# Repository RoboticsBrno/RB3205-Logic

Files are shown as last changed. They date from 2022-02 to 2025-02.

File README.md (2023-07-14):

# About Logic

Logic is a universal programmable toy designed for teaching programming
developed at [Robotárna](https://helceletka.cz/robotarna).

Logic resembles a game console. It has 105 RGB LEDs that can serve as a display, it
has numerous buttons and a buzzer. Under the hood, it is powered by the ESP32
microcontroller.

Kids (well, not only them) can create custom games and
learn programming while doing so. It is even possible to run multiplayer games as the on-board
processor features both, WiFi and Bluetooth 4.

This project was prepared for [Robotic Camp 2021](https://2021.robotickytabor.cz/) ­–
the page is available, however, in Czech. You will find more project there. You
can also see our [GitHub](https://github.com/RoboticsBrno) for find out more
about our other projects.

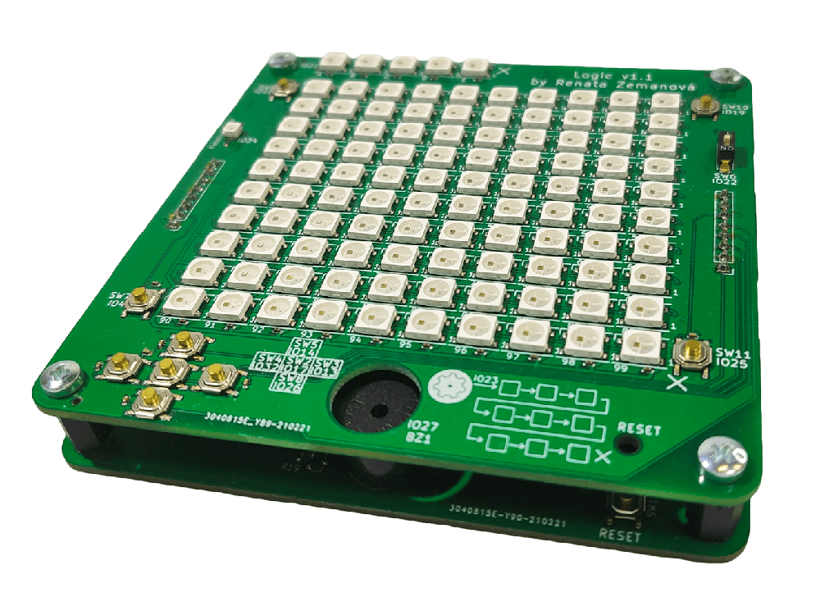
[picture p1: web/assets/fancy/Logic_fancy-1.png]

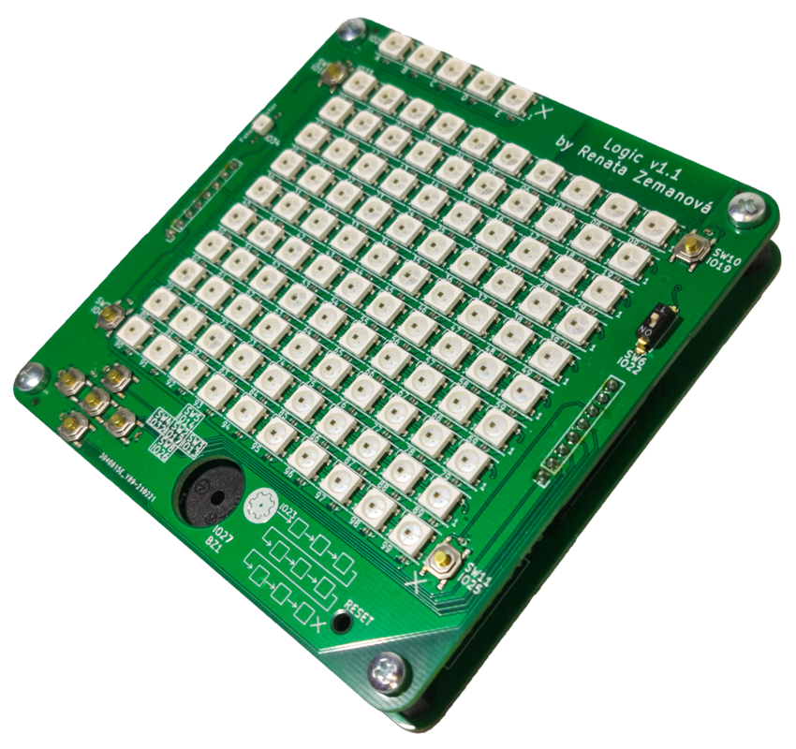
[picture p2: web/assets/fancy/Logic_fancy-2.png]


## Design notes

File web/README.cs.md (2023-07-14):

# Logic

Logic je univerzální programovatelná hračka určená pro výuku programování, kterou vyvinula [Robotárna](https://helceletka.cz/robotarna).

Logic připomíná herní konzoli. Je vybavený 105 RGB LED diodami, které mohou sloužit jako displej, má mnoho tlačítek a bzučák. Vnitřní část pohání mikrořadič ESP32.

Děti (no, nejen ony) mohou vytvářet vlastní hry a učit se přitom programovat. Je dokonce možné spouštět multiplayerové hry, protože vestavěný procesor podporuje jak WiFi, tak Bluetooth 4.

Tento projekt byl připraven pro [Robotický tábor 2021](https://2021.robotickytabor.cz/) – stránka je dostupná, avšak v češtině. Najdete tam více projektů. Můžete se také podívat na náš [GitHub](https://github.com/RoboticsBrno), kde se dozvíte více o našich dalších projektech.

## Verze HW

Existuje několik verzí HW, přičemž druhá verze představuje zásadní přepracování.

### Seznam změn:

#### v2.0

- nový čip ESP32 S3 (namísto "normálního" ESP32)
- slot pro [SD kartu](code/sdcard.md)
- konektor [PMOD](code/pmod.md) (standardizované rozhraní pro připojení různých periferií)
- přepracované uspořádání tlačítek s dvěma směrovými kříži
- piezo místo pouhého bzučáku (takže můžete přehrávat různé tóny)
- jasnější inteligentní LED

=== "Logic v2"
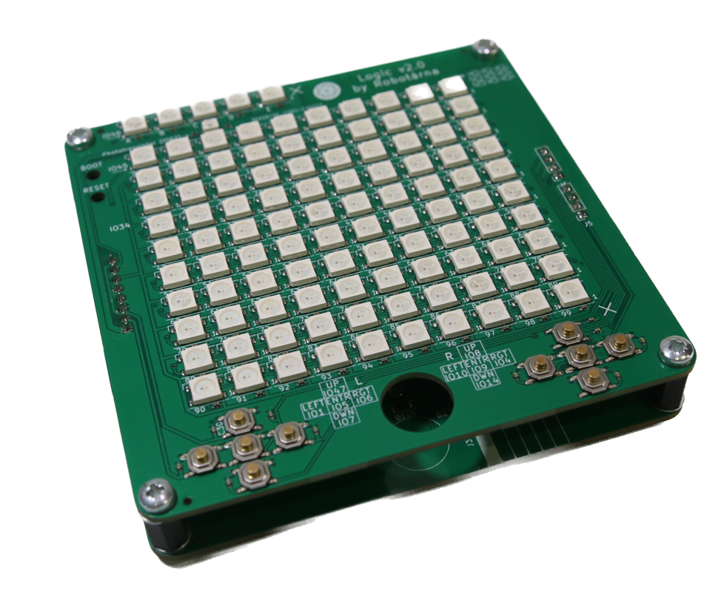
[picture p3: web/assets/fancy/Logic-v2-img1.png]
	
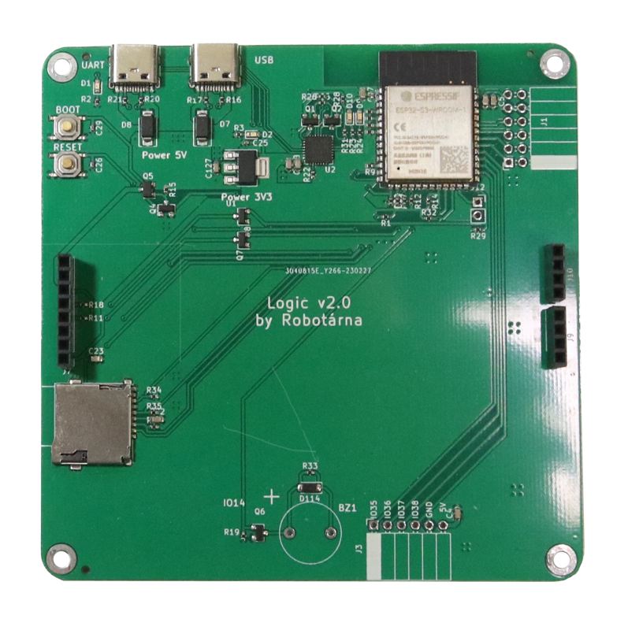
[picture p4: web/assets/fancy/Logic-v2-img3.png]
	
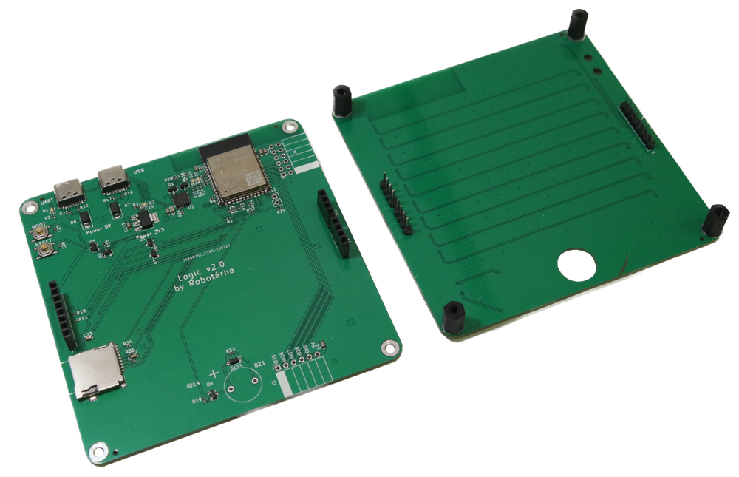
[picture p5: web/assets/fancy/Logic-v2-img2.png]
	

=== "Logic v1"
	RoboSvit schéma
	RoboSvit schéma

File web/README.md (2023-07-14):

# About Logic

Logic is a universal programmable toy designed for teaching programming
developed at [Robotárna](https://helceletka.cz/robotarna).

Logic resembles a game console. It has 105 RGB LEDs that can serve as a display, it
has numerous buttons and a buzzer. Under the hood, it is powered by the ESP32
microcontroller.

Kids (well, not only them) can create custom games and
learn programming while doing so. It is even possible to run multiplayer games as the on-board
processor features both, WiFi and Bluetooth 4.

This project was prepared for [Robotic Camp 2021](https://2021.robotickytabor.cz/) ­–
the page is available, however, in Czech. You will find more project there. You
can also see our [GitHub](https://github.com/RoboticsBrno) for find out more
about our other projects.

## HW revisions

There are multiple HW revisions out in the wild, with the v2 being a major overhaul.

### Changelog:

#### v2.0

- new ESP32 S3 chip (instead of "normal" ESP32)
- [SD Card slot](code/sdcard.md)
- [PMOD connector](code/pmod.md) (a standardized interface to connect various peripherials)
- revised button layout with two direction crosses
- piezo instead of just a buzzer (so you can play different tones)
- brighther smart LEDs

=== "Logic v2"
	RoboSvit schéma
	RoboSvit schéma
	RoboSvit schéma

=== "Logic v1"
	RoboSvit schéma
	RoboSvit schéma

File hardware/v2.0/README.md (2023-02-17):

# About Logic

## changes compared to V1.1:
- ESP32-S3
- SD card

<div align="center">
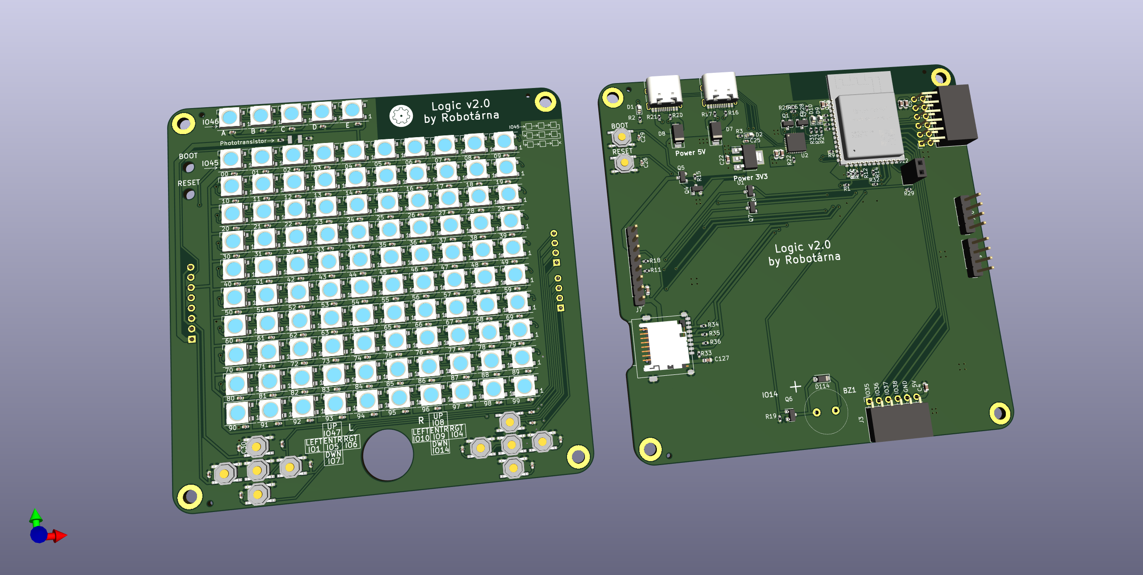
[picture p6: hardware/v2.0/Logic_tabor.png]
    
</div>

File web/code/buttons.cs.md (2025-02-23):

# Tlačítka

## Přímé čtení tlačítek

- **`buttons.read(gpio_num_t gpio)`** : 

## Názvy tlačítek
- `Enter`
- `Up`
- `Down`
- `Left`
- `Right`
- `LeftUp`
- `LeftDown`
- `RightUp`
- `RightDown`

## Příklad použití

```cpp
#include "Logic.hpp"
#include <iostream>

void logicMain() {
    while (true) {
        display.clear();

        if(buttons.read(Enter)) {
            display.drawSquareFilled(3, 3, 4, Rgb(255, 255, 255));    
        }
        else if(buttons.read(Right)) {
            display.drawSquareFilled(6, 3, 4, Rgb(255, 255, 255));
        }
        else if(buttons.read(Down)) {
            display.drawSquareFilled(3, 6, 4, Rgb(255, 255, 255));
        }
        else if(buttons.read(Left)) {
            display.drawSquareFilled(0, 3, 4, Rgb(255, 255, 255));
        }
        else if(buttons.read(Up)) {
            display.drawSquareFilled(3, 0, 4, Rgb(255, 255, 255));
        }
        display.show(30);
    }
}
```
# Registrace událostí na tlačítka

## buttons.priZmene (buttons.onChange)

```cpp
buttons.priZmene([](std::bitset<MaxID> aktualniStav, std::bitset<MaxID> zmenenaTlacitka) {
	if (zmenenaTlacitka[Up] == 1) {

		std::cout << "Tlačítko Nahoru se změnilo a teď je ";

		if (aktualniStav[Up] == 1) {
			std::cout << "zmáčknuté." << std::endl;
		} else {
			std::cout << "puštěné." << std::endl;
		}
	}
});

buttons.priZmene([](std::bitset<MaxID> aktualniStav) {
	std::cout << "Tlačítko Nahoru je nyní ";

	if (aktualniStav[Up] == 1) {
		std::cout << "zmáčknuté." << std::endl;
	} else {
		std::cout << "puštěné." << std::endl;
	}
});

buttons.priZmene([]() {
	std::cout << "Tlačítko bylo změněno. Není k dispozici více informací." << std::endl;
});

buttons.priZmene([](std::bitset<MaxID> aktualniStav, std::bitset<MaxID> zmenenaTlacitka) {
	std::cout << "Tohle uvidíte pouze pokud se změní tlačítko Dolů, a toto tlačítko je nyní ";

	if (aktualniStav[Down] == 1) {
		std::cout << "zmáčknuté." << std::endl;
	} else {
		std::cout << "puštěné." << std::endl;
	}
}, Down);

buttons.priZmene([](bool isPressed) {
	std::cout << "Tohle uvidíte pouze pokud se změní tlačítko Dolů" << std::endl;

	if (isPressed == 1) {
		std::cout << "zmáčknuté." << std::endl;
	} else {
		std::cout << "puštěné." << std::endl;
	}
}, Down);

buttons.onChange([]() {
	std::cout << "Tohle uvidíte pouze pokud se změní tlačítko Dolů" << std::endl;
}, Down);
```

## buttons.priStisku (buttons.onPress)

```cpp
buttons.priStisku([](std::bitset<MaxID> aktualniStav, std::bitset<MaxID> zmena) {
	std::cout << "Nějaké tlačítko bylo zmáčknuto. ";

	if (zmena[Right] == 1) {
		std::cout << "Bylo to tlačítko Vpravo" << std::endl;
	} else {
		std::cout << "Nebylo to tlačítko Vpravo" << std::endl;
	}
});

buttons.priStisku([](std::bitset<MaxID> aktualniStav) {
	std::cout << "Nějaké tlačítko bylo zmáčknuto. ";

	std::cout << "Tlačítka ";

	for(int i = 0; i < MaxID; i++) {
		if (aktualniStav[i] == 1) {
			std::cout << i << ", ";
		}
	}

	std::cout << "jsou nyní zmáčknutá." << std::endl;
});

buttons.priStisku([]() {
	std::cout << "Tlačítko bylo Zmáčknuto. Není k dispozici více informací." << std::endl;
});

buttons.priStisku([]() {
	std::cout << "Tohle uvidíte pouze pokud zmáčknete tlačítko Vlevo." << std::endl;
}, Left);
```

## buttons.priUvolneni (.onRelease)

```cpp
buttons.priUvolneni([](std::bitset<MaxID> aktualniStav, std::bitset<MaxID> zmena) {
	std::cout << "Tlačítko bylo puštěno. ";

	if (zmena[Right] == 1) {
		std::cout << "Bylo to tlačítko Vpravo" << std::endl;
	} else {
		std::cout << "Nebylo to tlačítko Vpravo" << std::endl;
	}
});

buttons.priUvolneni([](std::bitset<MaxID> aktualniStav) {
	std::cout << "Tlačítko bylo puštěno. ";

	std::cout << "Tlačítka ";

	for(int i = 0; i < MaxID; i++) {
		if (aktualniStav[i] == 0) {
			std::cout << i << ", ";
		}
	}

	std::cout << "jsou nyní puštěná." << std::endl;
});

buttons.priUvolneni([]() {
	std::cout << "Tlačítko bylo uvolněno. Není k dispozici více informací." << std::endl;
});

buttons.priUvolneni([]() {
	std::cout << "Tohle uvidíte pouze pokud pustíte tlačítko Vlevo." << std::endl;
}, Left);
```

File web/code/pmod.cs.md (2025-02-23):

# PMOD konektor

Logic v2 a novější má PMOD konektor, který je standardizovaným způsobem pro připojení
různých periferií.

!!! info

    HW revize 1.x nemají PMOD konektor.

## Zapojení pinů

Zapojení pinů je vyznačeno na spodní straně desky bílými popisky.

!!! warning

    Popisek 5V je chybný a měl by místo toho být `VCC` – napětí je možné konfigurovat, viz níže.

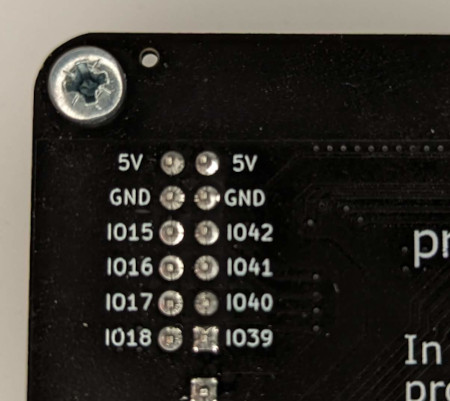
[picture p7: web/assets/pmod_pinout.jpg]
PMOD zapojení pinů


## Nastavení napětí

U HW revize v2.0 se nachází tři pinové lišty pro nastavení napětí na PMOD VCC.
Bohužel nejsou označené, takže zde jsou fotografie nastavení pro 3,3 V a 5 V:

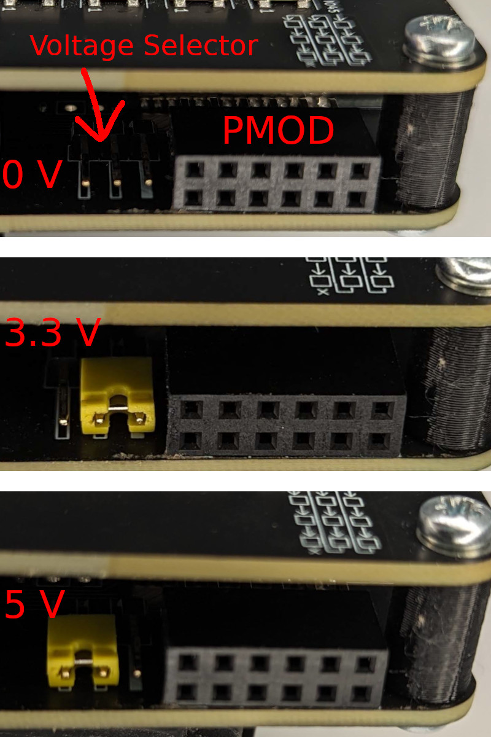
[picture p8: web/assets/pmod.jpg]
PMOD voltage


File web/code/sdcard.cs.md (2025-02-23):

# SD karta

Deska Logic v2 je vybavena slotem pro SD kartu, který můžete použít ke čtení nebo zápisu dat na kartu s FAT32 formátem.

!!! info

    HW revize 1.x nemají slot na SD kartu.

!!! danger "SDMMC je nefunkční"

    U HW revize 2.0 je režim SDMMC nefunkční. K přístupu na SD kartu je nutné použít protokol SDSPI. Tato chyba bude opravena v [pozdější HW revizi](https://github.com/RoboticsBrno/RB3205-Logic/issues/1).

## Zapojení pinů

| Pin | SD SPI | {--SD MMC--} |
| --- | --- | --- |
| 11  | MOSI | {--CMD--} |
| 12  | SCLK | {--CLK--} |
| 13  | MISO | {--D0--} |
| 3 | CS | {--CD--} |

## Ukázkový inicializační kód

Pro SD kartu je zapotřebí delší kód pro inicializaci, ale poté můžete používat standardní funkce jazyka C nebo C++ pro přístup k souborovému systému, podobně jako na běžném počítači.

```cpp
#include "Logic.hpp"
#include <iostream>

#include "esp_vfs_fat.h"
#include <dirent.h>
#include <string.h>
#include <sys/stat.h>
#include <sys/unistd.h>

#define EXAMPLE_MAX_CHAR_SIZE 64

static const char* TAG = "example";

#define MOUNT_POINT "/sdcard"

void logicMain() {
    esp_err_t ret;

    // Inicializace SPI sběrnice
    spi_bus_config_t bus_cfg = {};
    bus_cfg.mosi_io_num = GPIO_NUM_11;
    bus_cfg.miso_io_num = GPIO_NUM_13;
    bus_cfg.sclk_io_num = GPIO_NUM_12;
    bus_cfg.quadwp_io_num = -1;
    bus_cfg.quadhd_io_num = -1;
    bus_cfg.max_transfer_sz = 4000;

    ret = spi_bus_initialize(SPI2_HOST, &bus_cfg, SPI_DMA_CH_AUTO);
    if (ret != ESP_OK) {
        ESP_LOGE(TAG, "Nepodařilo se inicializovat sběrnici.");
        vTaskDelay(1000 / portTICK_PERIOD_MS);
        return;
    }

    /// Možnosti pro souborový systém
    esp_vfs_fat_mount_config_t mount_config = {};
    mount_config.max_files = 5;
    mount_config.allocation_unit_size = 16 * 1024;

    sdmmc_card_t* card;
    const char mount_point[] = MOUNT_POINT;
    ESP_LOGI(TAG, "Inicializace SD karty");

    // Inicializace SDSPI
    sdmmc_host_t host = SDSPI_HOST_DEFAULT();
    host.slot = SPI2_HOST;

    sdspi_device_config_t dev_cfg = SDSPI_DEVICE_CONFIG_DEFAULT();
    dev_cfg.gpio_cs = GPIO_NUM_3;

    ESP_LOGI(TAG, "Připojování souborového systému");
    ret = esp_vfs_fat_sdspi_mount(mount_point, &host, &dev_cfg, &mount_config, &card);

    if (ret != ESP_OK) {
        if (ret == ESP_FAIL) {
            ESP_LOGE(TAG, "Nepodařilo se připojit souborový systém. "
                          "Pokud chcete kartu naformátovat, aktivujte volbu EXAMPLE_FORMAT_IF_MOUNT_FAILED v menuconfig.");
        } else {
            ESP_LOGE(TAG, "Nepodařilo se inicializovat kartu (%s). "
                          "Ujistěte se, že linky SD karty mají zapojené pull-up rezistory.",
                esp_err_to_name(ret));
        }
        return;
    }
    ESP_LOGI(TAG, "Souborový systém byl připojen");

    // Vypsání obsahu kořenového adresáře
    DIR* dir = opendir(mount_point);
    struct dirent* ent;
    while ((ent = readdir(dir)) != NULL) {
        printf("Soubor %s %d\n", ent->d_name, ent->d_type);
    }
    closedir(dir);

    while (true) {
        delay(100);
    }
}
```

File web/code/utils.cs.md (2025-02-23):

# Pomocné funkce

## Práce s časem

- **`#!cpp void delay(uint32_t ms)`** : Počká po stanovenou dobu v milisekundách
- **`#!cpp void waitSeconds(float seconds)`** : Počká po stanovenou dobu v sekundách
- **`#!cpp uint32_t millis()`** : Vrátí počet milisekund od startu
- **`#!cpp float seconds()`** : Vrátí počet sekund od startu

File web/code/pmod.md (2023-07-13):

# PMOD connector

The Logic v2 and newer has a PMOD connector, which is a standardized way to connect various peripherials.

!!! info

    The 1.x HW revisions do not have PMOD connector.

## Pinout

Pinout is visible from the underside of the board as white labels.

!!! warning

    The 5V label is wrong, and it should say `VCC` instead - the voltage is configurable, see below.

PMOD pinout

## Voltage setting

On the v2.0 HW revision, there are three pinheads to be used to set the voltage on PMOD VCC.
They are unfortunatelly without labels, so here are photos of the 3.3 V and 5 V settings:

PMOD voltage

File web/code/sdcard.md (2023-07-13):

# SD card

The Logic v2 board has an sdcard slot which you can use to store or load data from FAT32-formatted cards.

!!! info

    The 1.x HW revisions do not have SD card slot.

!!! danger "SDMMC is broken"

    On the 2.0 HW revision, the SDMMC mode is broken. You have to use SDSPI protocol to access the SD card. This will be fixed in a [later HW revision](https://github.com/RoboticsBrno/RB3205-Logic/issues/1).

## Pinout

| Pin | SD SPI | {--SD MMC--} |
| --- | --- | --- |
| 11  | MOSI | {--CMD--} |
| 12  | SCLK | {--CLK--} |
| 13  | MISO | {--D0--} |
| 3 | CS | {--CD--} |

## Example init code

The SD card has some long-ish init code, but after that, you may use standard C or C++ functions to access the filesystem, just like on a desktop.

```cpp
#include "Logic.hpp"
#include <iostream>

#include "esp_vfs_fat.h"
#include <dirent.h>
#include <string.h>
#include <sys/stat.h>
#include <sys/unistd.h>

#define EXAMPLE_MAX_CHAR_SIZE 64

static const char* TAG = "example";

#define MOUNT_POINT "/sdcard"

void logicMain() {
    esp_err_t ret;

    // SPI BUS init
    spi_bus_config_t bus_cfg = {};
    bus_cfg.mosi_io_num = GPIO_NUM_11;
    bus_cfg.miso_io_num = GPIO_NUM_13;
    bus_cfg.sclk_io_num = GPIO_NUM_12;
    bus_cfg.quadwp_io_num = -1;
    bus_cfg.quadhd_io_num = -1;
    bus_cfg.max_transfer_sz = 4000;

    ret = spi_bus_initialize(SPI2_HOST, &bus_cfg, SPI_DMA_CH_AUTO);
    if (ret != ESP_OK) {
        ESP_LOGE(TAG, "Failed to initialize bus.");
        vTaskDelay(1000 / portTICK_PERIOD_MS);
        return;
    }

    /// FS options
    esp_vfs_fat_mount_config_t mount_config = {};
    mount_config.max_files = 5;
    mount_config.allocation_unit_size = 16 * 1024;

    sdmmc_card_t* card;
    const char mount_point[] = MOUNT_POINT;
    ESP_LOGI(TAG, "Initializing SD card");

    // SDSPI init
    sdmmc_host_t host = SDSPI_HOST_DEFAULT();
    host.slot = SPI2_HOST;

    sdspi_device_config_t dev_cfg = SDSPI_DEVICE_CONFIG_DEFAULT();
    dev_cfg.gpio_cs = GPIO_NUM_3;

    ESP_LOGI(TAG, "Mounting filesystem");
    ret = esp_vfs_fat_sdspi_mount(mount_point, &host, &dev_cfg, &mount_config, &card);

    if (ret != ESP_OK) {
        if (ret == ESP_FAIL) {
            ESP_LOGE(TAG, "Failed to mount filesystem. "
                          "If you want the card to be formatted, set the EXAMPLE_FORMAT_IF_MOUNT_FAILED menuconfig option.");
        } else {
            ESP_LOGE(TAG, "Failed to initialize the card (%s). "
                          "Make sure SD card lines have pull-up resistors in place.",
                esp_err_to_name(ret));
        }
        return;
    }
    ESP_LOGI(TAG, "Filesystem mounted");

    // List root directory
    DIR* dir = opendir(mount_point);
    struct dirent* ent;
    while ((ent = readdir(dir)) != NULL) {
        printf("File %s %d\n", ent->d_name, ent->d_type);
    }
    closedir(dir);

    while (true) {
        delay(100);
    }
}

```

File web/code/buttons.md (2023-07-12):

# Buttons

## Direct Button Reading

- **`#!cpp buttons.read(gpio_num_t gpio)`** :

## Button Names
- `Enter`
- `Up`
- `Down`
- `Left`
- `Right`
- `LeftUp`
- `LeftDown`
- `RightUp`
- `RightDown`

## Example Usage

```cpp
#include "Logic.hpp"
#include <iostream>

void logicMain() {
    while (true) {
        display.clear();

        if(buttons.read(Enter)) {
            display.drawSquareFilled(3, 3, 4, Rgb(255, 255, 255));
        }
        else if(buttons.read(Right)) {
            display.drawSquareFilled(6, 3, 4, Rgb(255, 255, 255));
        }
        else if(buttons.read(Down)) {
            display.drawSquareFilled(3, 6, 4, Rgb(255, 255, 255));
        }
        else if(buttons.read(Left)) {
            display.drawSquareFilled(0, 3, 4, Rgb(255, 255, 255));
        }
        else if(buttons.read(Up)) {
            display.drawSquareFilled(3, 0, 4, Rgb(255, 255, 255));
        }
        display.show(30);
    }
}
```
# Event-based Button Handling

## buttons.onChange

```cpp
buttons.onChange([](std::bitset<MaxID> currentState, std::bitset<MaxID> buttonChange) {
	if (buttonChange[up] == 1) {

		std::cout << "Button Up has changed and is now ";

		if (currentState[Up] == 1) {
			std::cout << "pressed." << std::endl;
		} else {
			std::cout << "released." << std::endl;
		}
	}
});

buttons.onChange([](std::bitset<MaxID> currentState) {
	std::cout << "Button Up is now ";

	if (currentState[Up] == 1) {
		std::cout << "pressed." << std::endl;
	} else {
		std::cout << "released." << std::endl;
	}
});

buttons.onChange([]() {
		std::cout << "A button has changed. No more information available" << std::endl;
	});

buttons.onChange([](std::bitset<MaxID> currentState, std::bitset<MaxID> buttonChange) {
	std::cout << "You will see this only when Button Down changes, and the button is now ";

	if (currentState[Down] == 1) {
		std::cout << "pressed." << std::endl;
	} else {
		std::cout << "released." << std::endl;
	}
}, Down);

buttons.onChange([](bool isPressed) {
	std::cout << "You will see this only when Button Down changes" << std::endl;

	if (isPressed == 1) {
		std::cout << "pressed." << std::endl;
	} else {
		std::cout << "released." << std::endl;
	}
}, Down);

buttons.onChange([]() {
	std::cout << "You will see this only when Button Down changes" << std::endl;
}, Down);
```

## buttons.onPress

```cpp
buttons.onPress([](std::bitset<MaxID> currentState, std::bitset<MaxID> changed) {
	std::cout << "A button has been pressed. ";

	if (changed[Right] == 1) {
		std::cout << "It was the Right button" << std::endl;
	} else {
		std::cout << "It was not the Right button" << std::endl;
	}
});

buttons.onPress([](std::bitset<MaxID> currentState) {
	std::cout << "A button has been pressed. ";

	std::cout << "Buttons ";

	for(int i = 0; i < MaxID; i++) {
		if (currentState[i] == 1) {
			std::cout << i << ", ";
		}
	}

	std::cout << "are now pressed." << std::endl;
});

buttons.onPress([]() {
	std::cout << "A button has been pressed. No more information available" << std::endl;
});

buttons.onPress([]() {
	std::cout << "You will see this only when Button Left get pressed down." << std::endl;
}, Left);
```

## buttons.onRelease

```cpp
buttons.onRelease([](std::bitset<MaxID> currentState, std::bitset<MaxID> changed) {
	std::cout << "A button has been released. ";

	if (changed[Right] == 0) {
		std::cout << "It was the Right button" << std::endl;
	} else {
		std::cout << "It was not the Right button" << std::endl;
	}
});

buttons.onRelease([](std::bitset<MaxID> currentState) {
	std::cout << "A button has been released. ";

	std::cout << "Buttons ";

	for(int i = 0; i < MaxID; i++) {
		if (currentState[i] == 0) {
			std::cout << i << ", ";
		}
	}

	std::cout << "are now released." << std::endl;
});

buttons.onRelease([]() {
	std::cout << "A button has been released. No more information available" << std::endl;
});

buttons.onRelease([]() {
	std::cout << "You will see this only when Button Left gets released." << std::endl;
}, Left);
```

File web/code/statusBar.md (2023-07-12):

# Status bar

Status bar is the top row of 5 LEDs marked as A-E.

- **`#!cpp void setState(int state)`** : Set progress
- **`#!cpp int state()`** : Return current state
- **`#!cpp void setColor(Rgb color)`** : Set the color of status bar
- **`#!cpp Rgb color()`** : Return current color of status bar
- **`#!cpp void show(int intensity = 255)`** : Show current frame/state
- **`#!cpp void clear()`** : Clear the display
- **`#!cpp Rgb& at(int x)`** : Return pixel at given position

## Example

```cpp
#include "Logic.hpp"
#include <iostream>

void logicMain() {
    while (true) {
        statusBar.setColor(Rgb(255, 0, 0));
        statusBar.setState(4);

        statusBar.show(30);
        delay(3000);
        statusBar.clear();

        statusBar.setColor(Rgb(0, 255, 0));
        statusBar.setState(2);

        statusBar.show(30);
        delay(3000);
        statusBar.clear();

        statusBar.at(4) = Rgb(0, 0, 255);

        statusBar.show(30);
        delay(3000);
        statusBar.clear();

        statusBar.at(0) = Rgb(255, 0, 0);
        statusBar.at(1) = Rgb(0, 255, 0);
        statusBar.at(2) = Rgb(0, 0, 255);

        statusBar.show(30);
        delay(3000);
        statusBar.clear();
    }
}
```

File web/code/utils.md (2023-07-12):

# Utilities

## Handling time

- **`#!cpp void delay(uint32_t ms)`** : Wait for the specified number of milliseconds
- **`#!cpp void waitSeconds(float seconds)`** : Wait for the specified number of seconds
- **`#!cpp uint32_t millis()`** : Returns time since boot in milliseconds
- **`#!cpp float seconds()`** : Returns time since boot in seconds

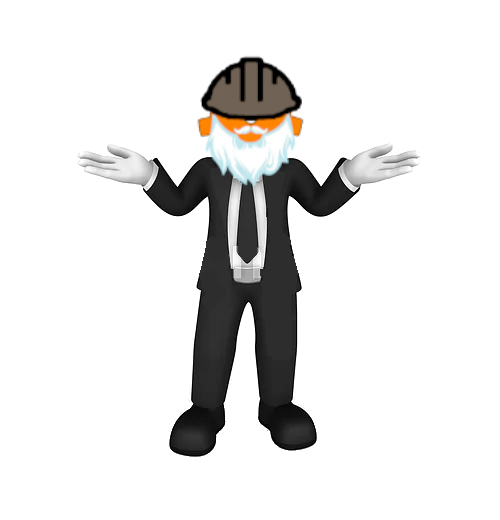
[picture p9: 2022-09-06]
web/assets/404V.png

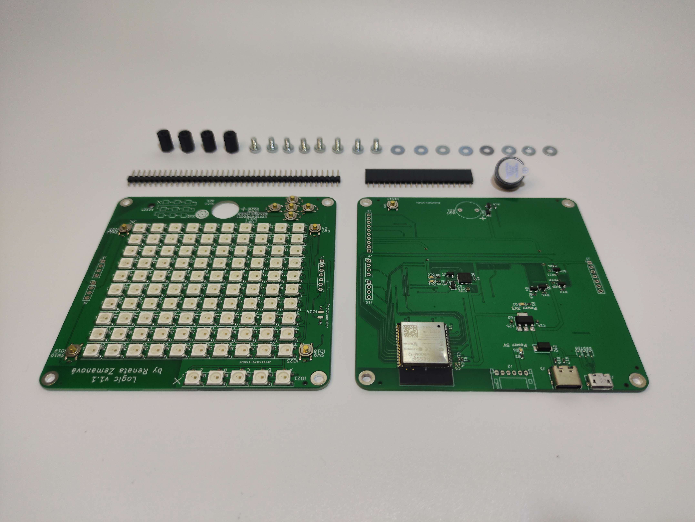
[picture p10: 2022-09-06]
web/assets/logic-01.jpg

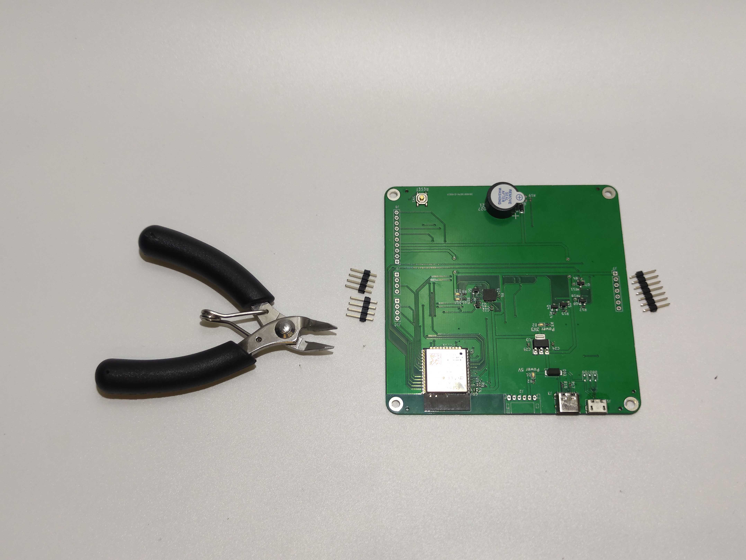
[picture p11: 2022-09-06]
web/assets/logic-08.jpg

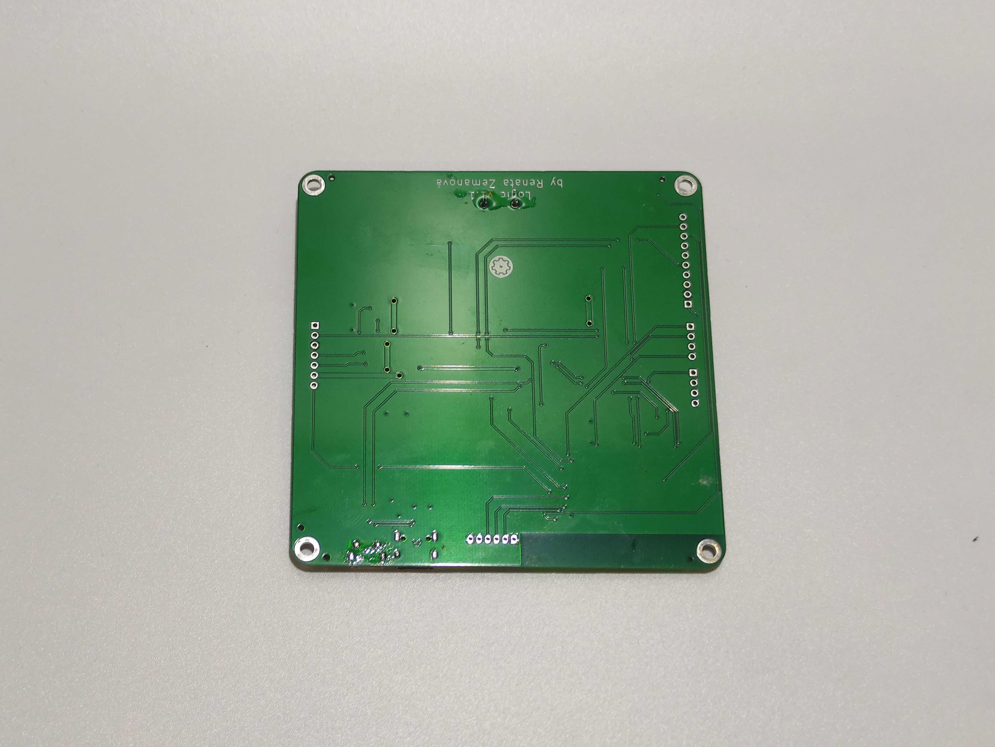
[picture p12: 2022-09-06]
web/assets/logic-05.jpg

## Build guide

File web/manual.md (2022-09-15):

# Assembly Manual

If you got your Logic as a kit, we provide you with the following step-by-step
guide on its assembly. To assemble it, you will need the following:

- a soldering iron
- pliers
- philips screwdriver
- Xacto knife

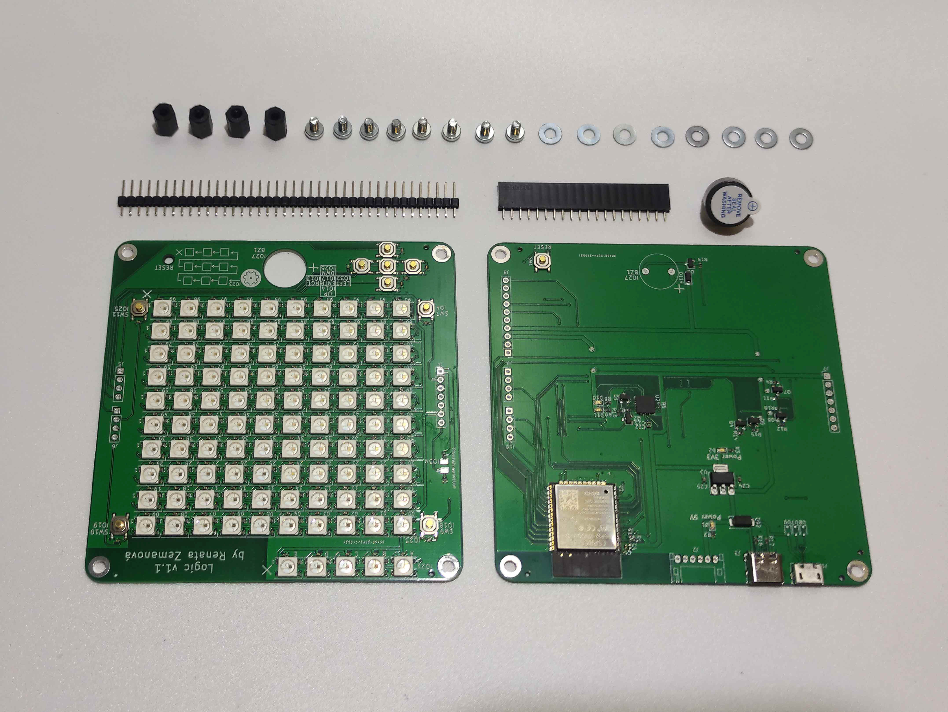
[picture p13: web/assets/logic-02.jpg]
<br>
1. Make sure you have all the material shown in the photo.
<hr>

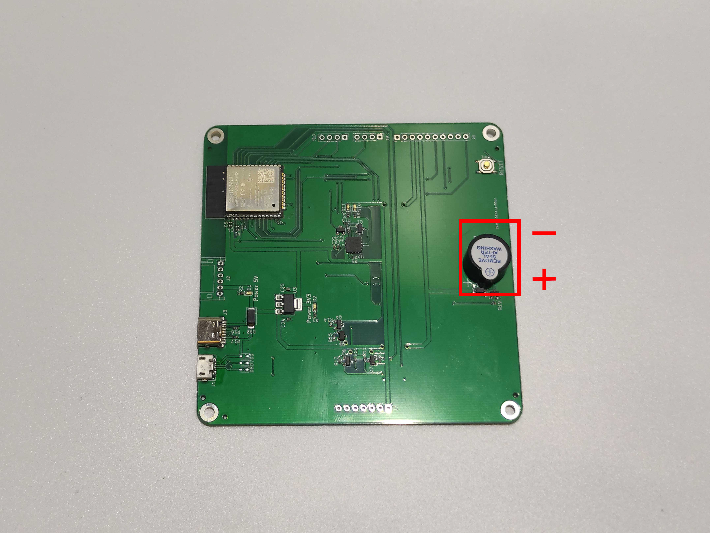
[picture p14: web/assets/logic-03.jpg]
<br>
2. Insert the buzzer into the board. Make sure that the polarity matches (the
   `+` smybol on the board matches with the `+` symbol on the buzzer).
<hr>

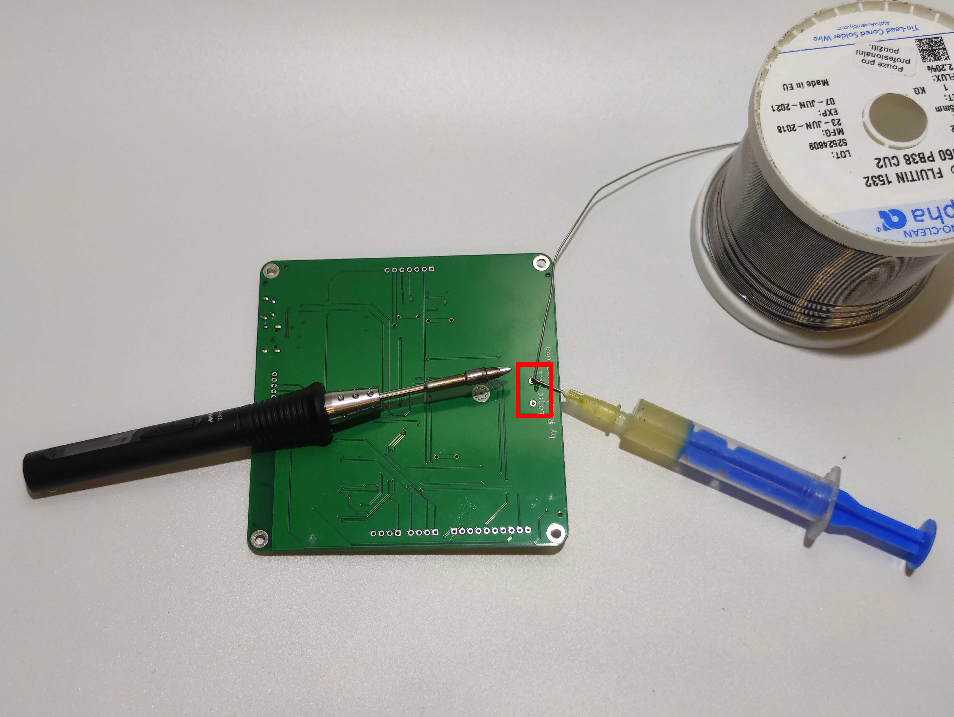
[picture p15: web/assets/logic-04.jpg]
<br>
3. Solder the buzzer's leads to the board.
<hr>

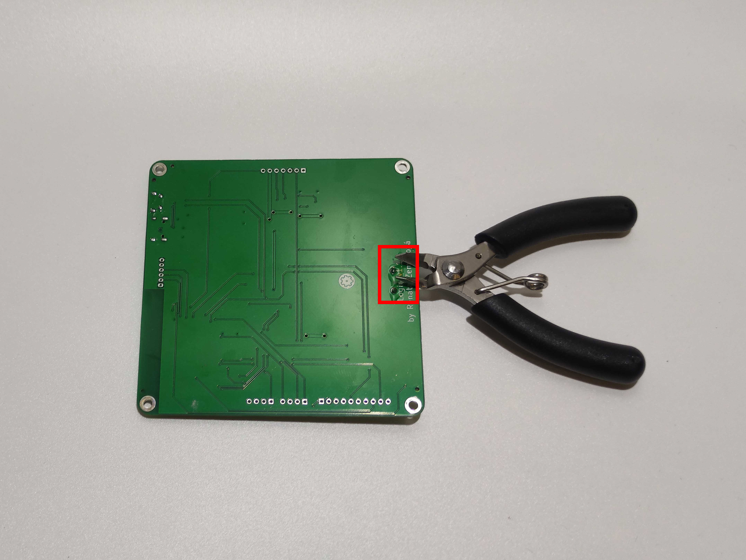
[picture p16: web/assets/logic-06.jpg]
<br>
4. Trim the buzzer leads.
<hr>

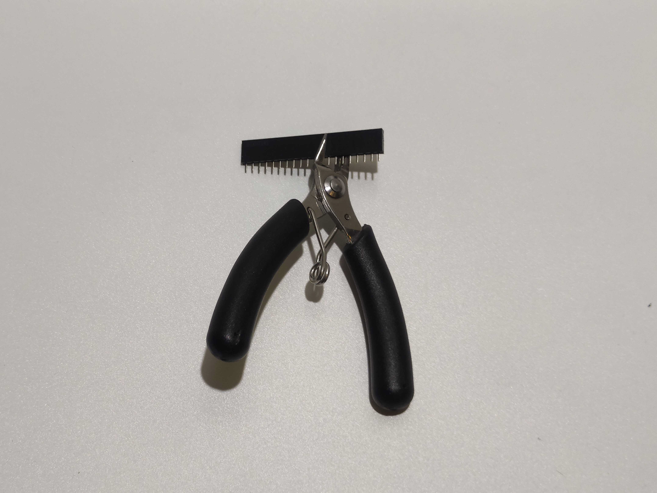
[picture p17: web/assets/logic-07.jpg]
<br>
5. Cut pin headers and pin sockets as follows:

- 2× pin headers and sockets with 4 pins
- 1× pin header and a socket with 7 pins
<hr>

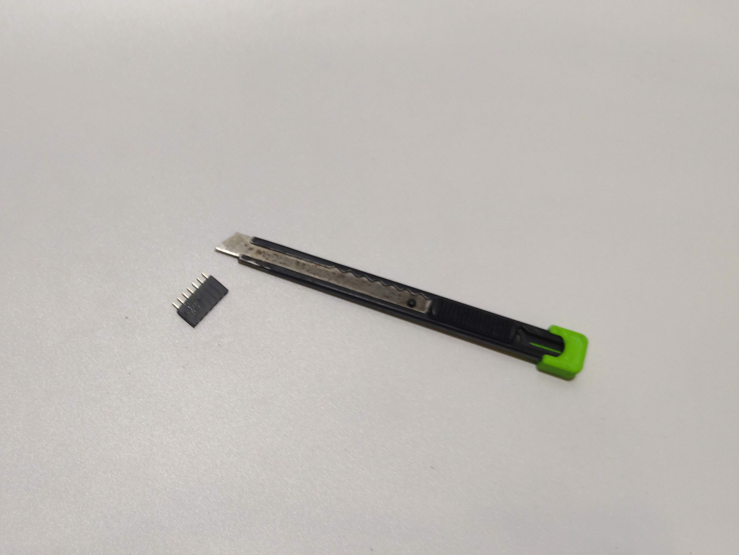
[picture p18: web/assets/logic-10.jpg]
<br>
6. Trim any burrs on the headers and sockets using an Xacto knife.
<hr>

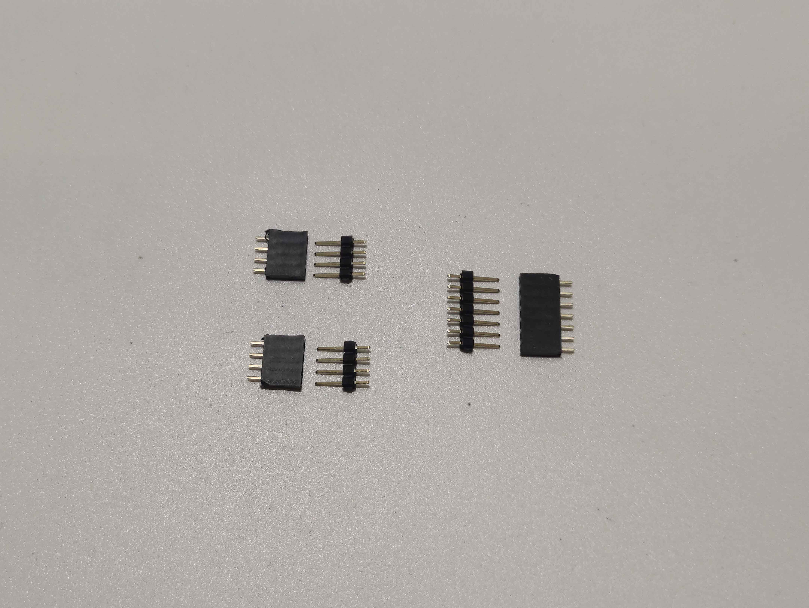
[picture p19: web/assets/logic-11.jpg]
<br>
7. Finished headers and sockets.
<hr>

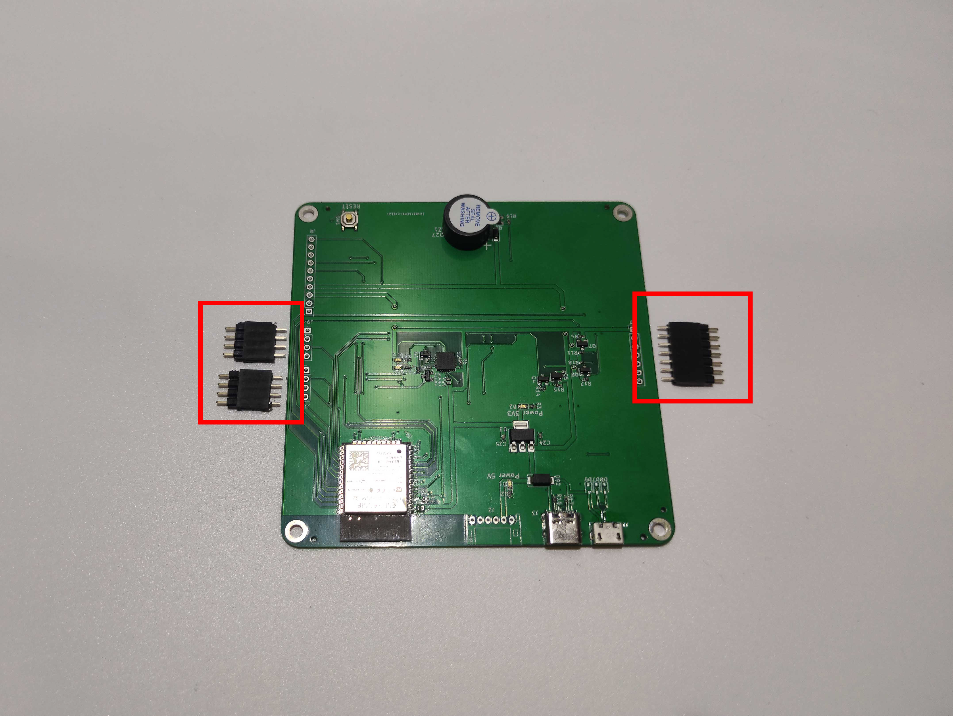
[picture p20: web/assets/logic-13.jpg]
<br>
8. Put pin headers inside the sockets.
<hr>

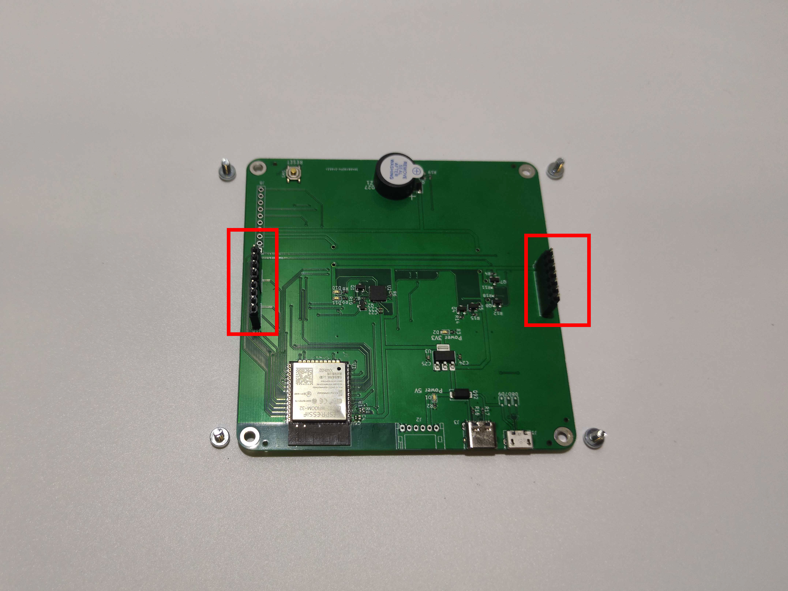
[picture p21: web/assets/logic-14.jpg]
<br>
9. Put the header inside the corresponding pads in the board.
<hr>

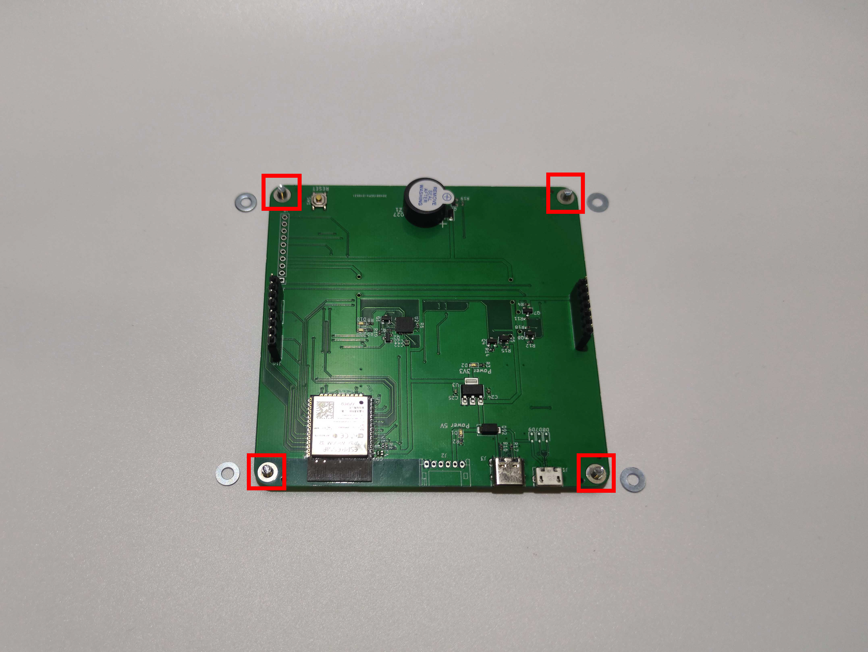
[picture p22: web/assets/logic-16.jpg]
<br>
10.  Insert the 4 M3 screws into the board and prepare washers.
<hr>

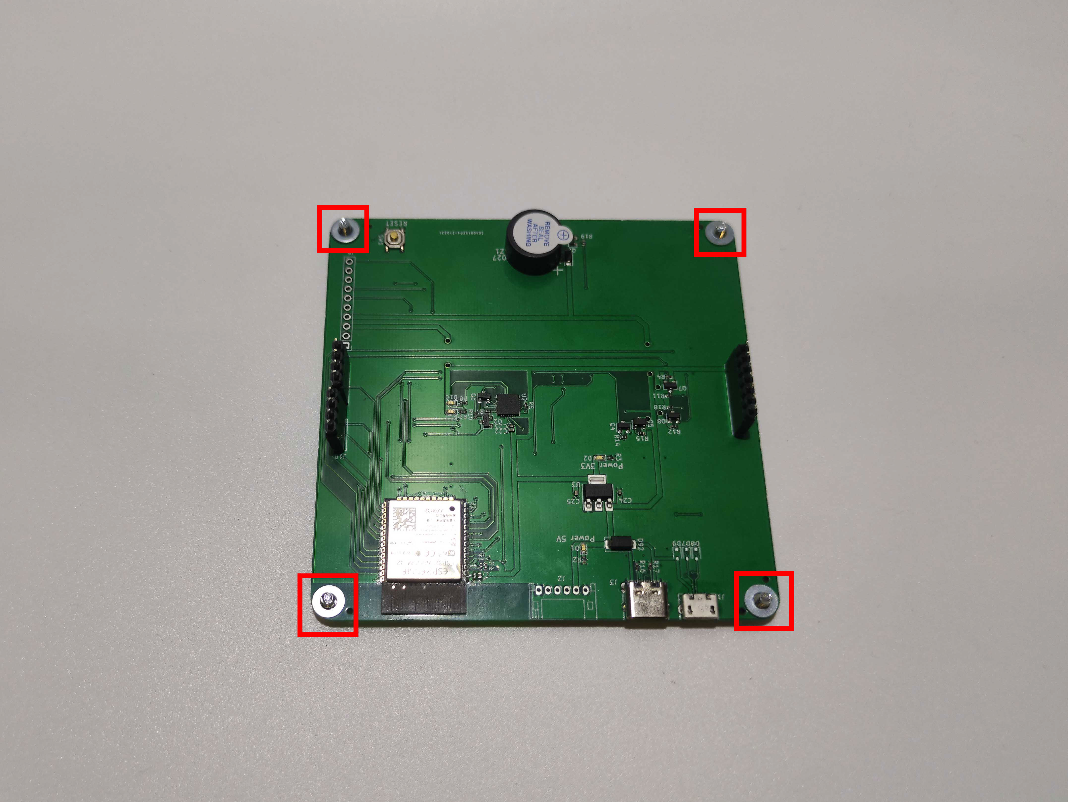
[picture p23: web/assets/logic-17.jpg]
<br>
11. Insert washers onto the screws.
<hr>

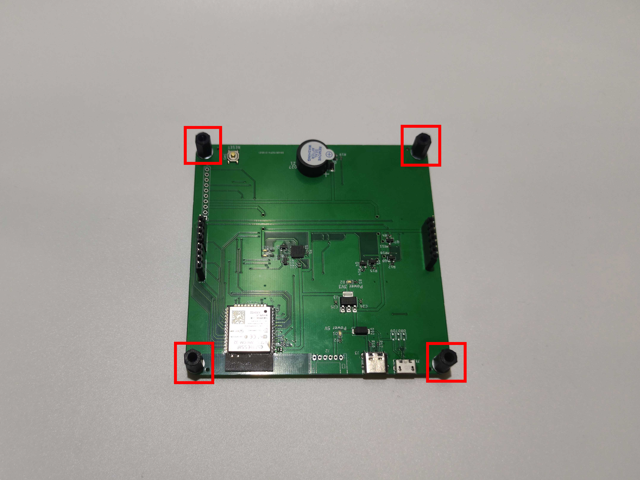
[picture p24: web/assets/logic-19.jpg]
<br>
12. Screw 4 plastic spacers on the screws.
<hr>

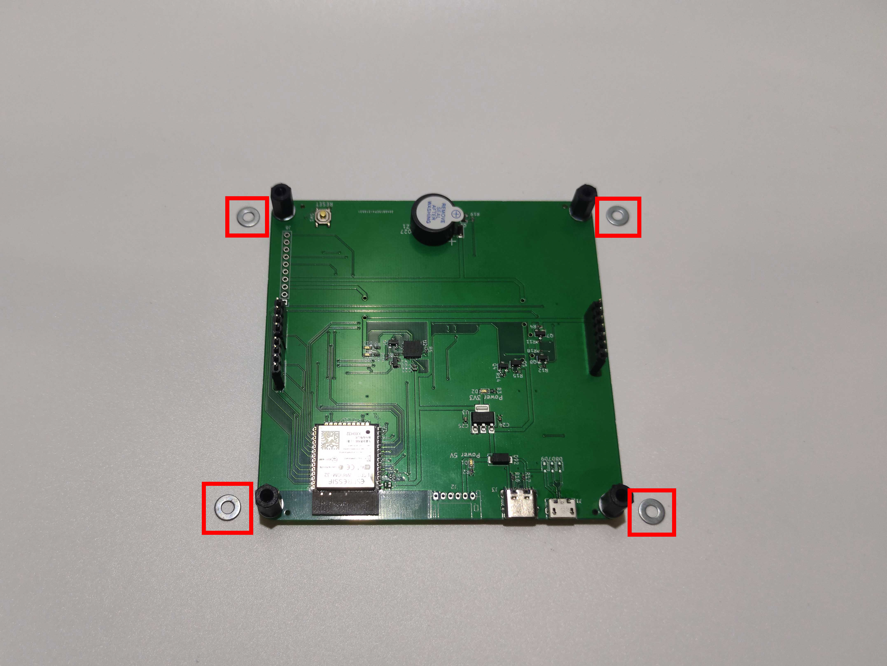
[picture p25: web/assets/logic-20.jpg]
<br>
13.  Prepare 4 washers.
<hr>

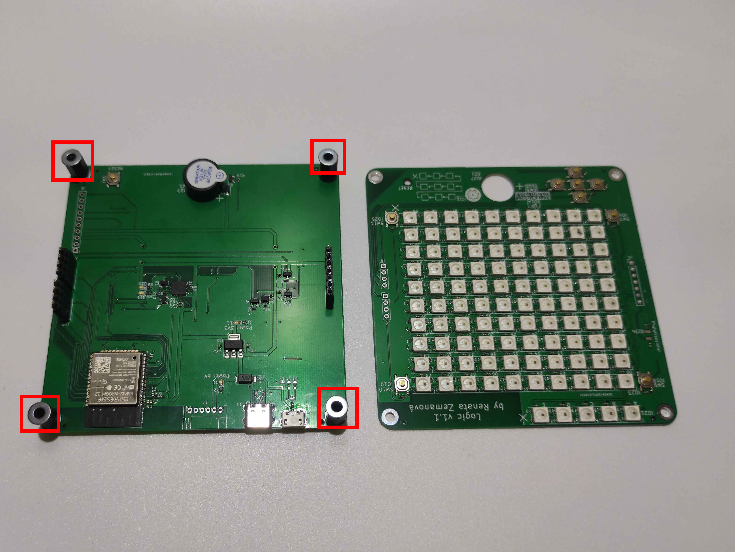
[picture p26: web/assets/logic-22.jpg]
<br>
14.  Place the washers on the spacers.
<hr>

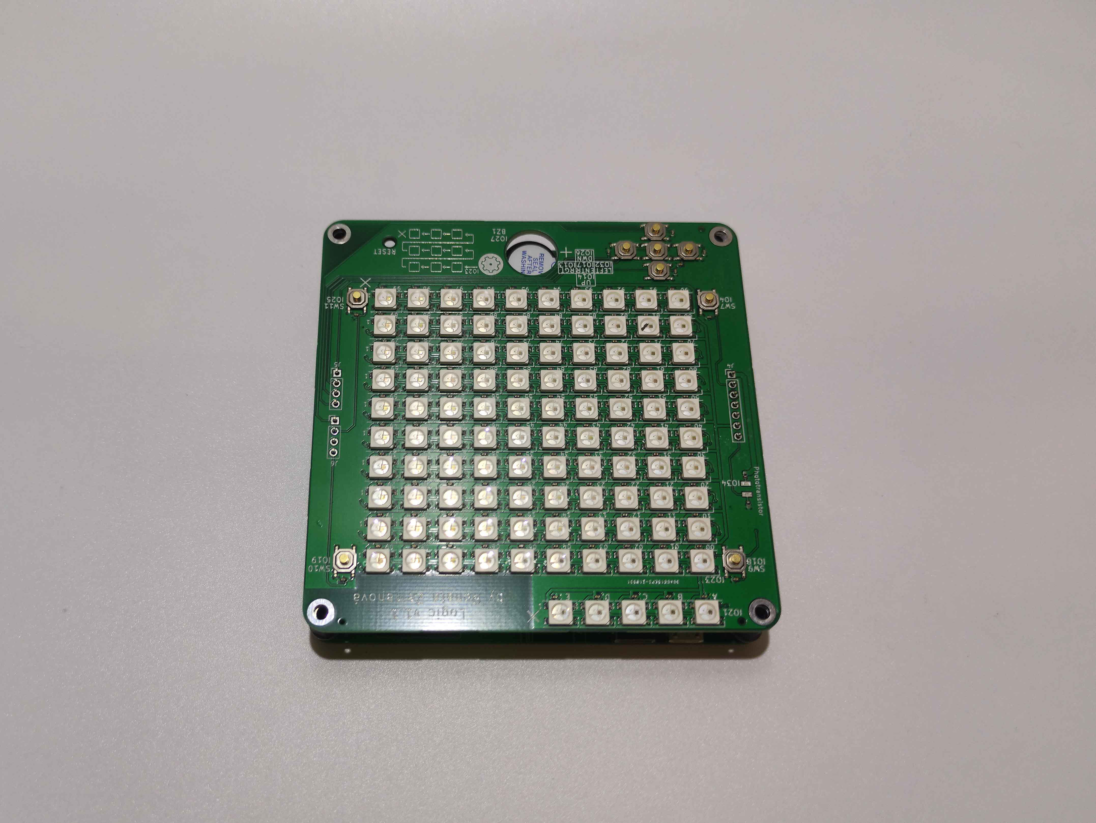
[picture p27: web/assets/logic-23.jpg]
<br>
15.  Put the top board on the assembly.
<hr>

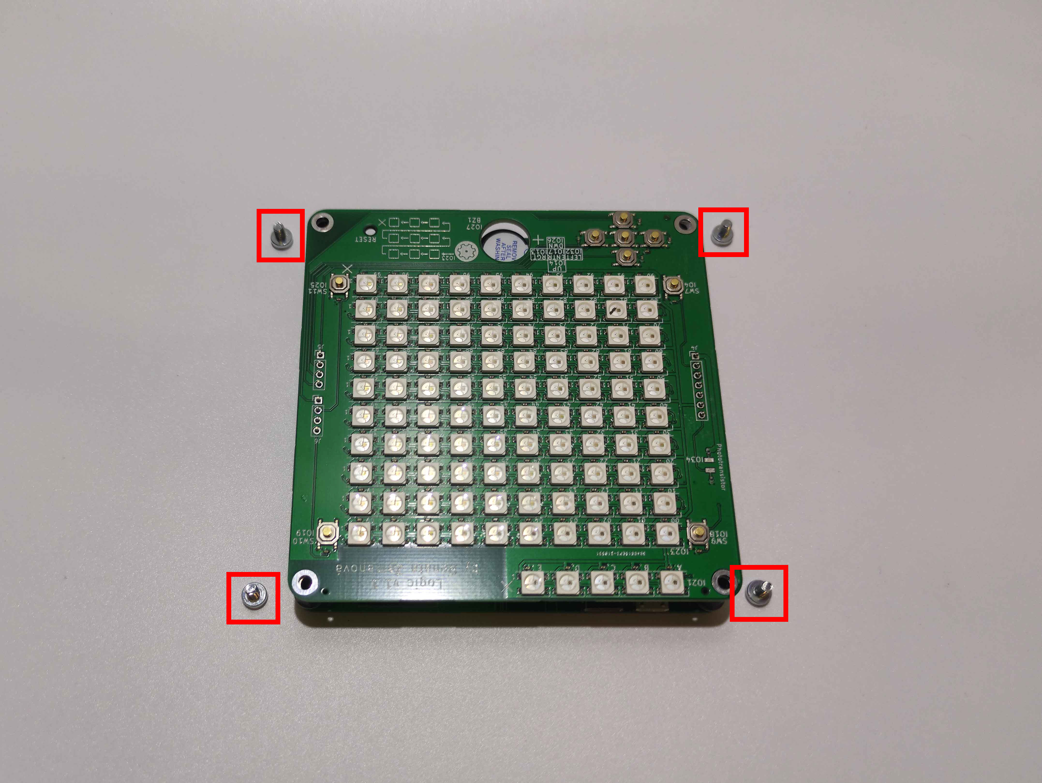
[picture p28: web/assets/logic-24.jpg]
<br>
16. Prepare 4 M3 screws.
<hr>

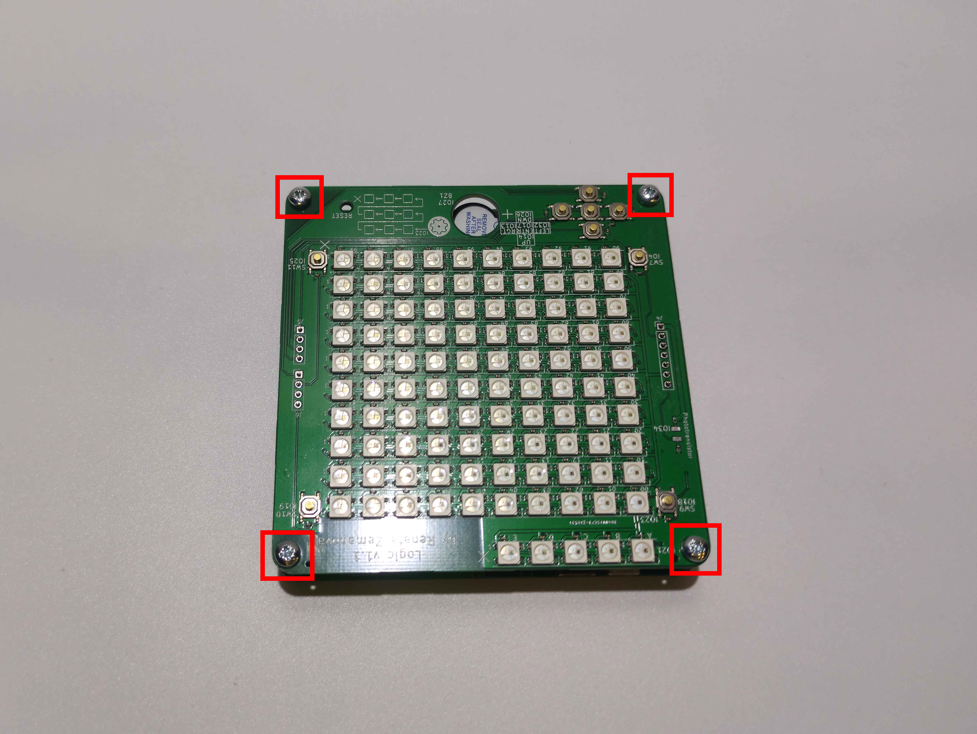
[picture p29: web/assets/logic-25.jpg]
<br>
17. Tighten the screws.
<hr>

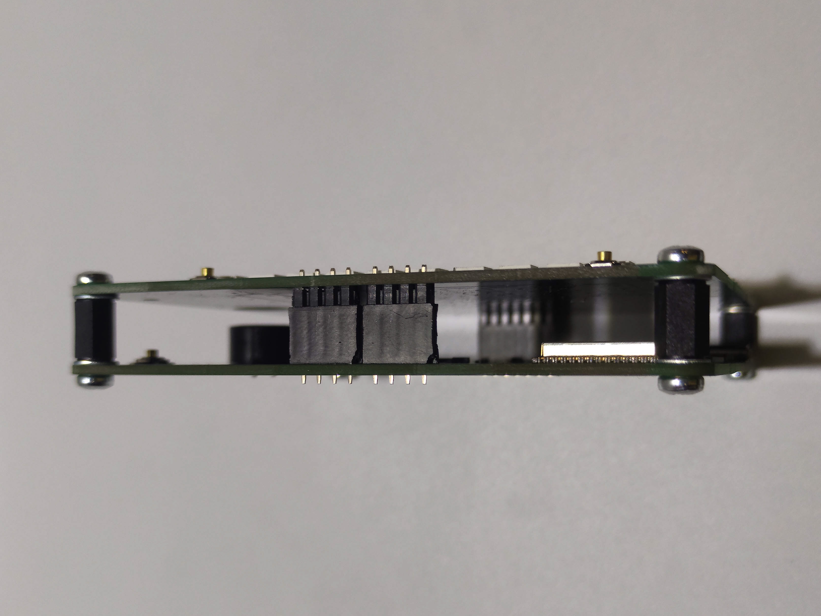
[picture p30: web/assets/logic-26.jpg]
<br>
18.  Make sure that the headers are inserted into the top board and the sockets
     are inserted in the bottom board.
<hr>

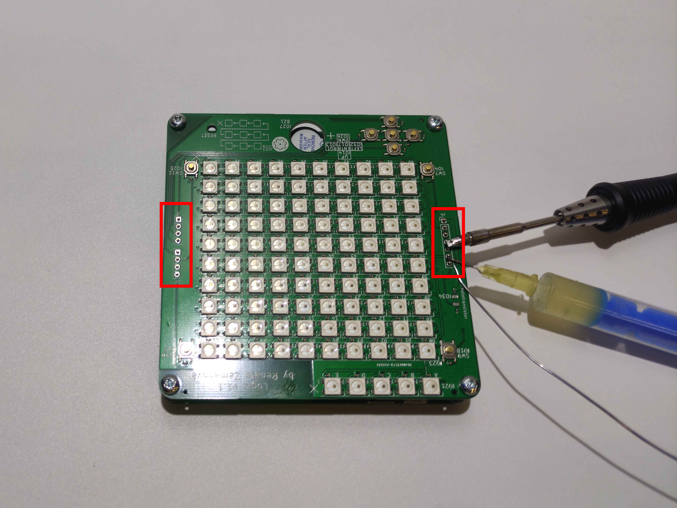
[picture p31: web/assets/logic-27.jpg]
<br>
19. Solder the pin headers.
<hr>

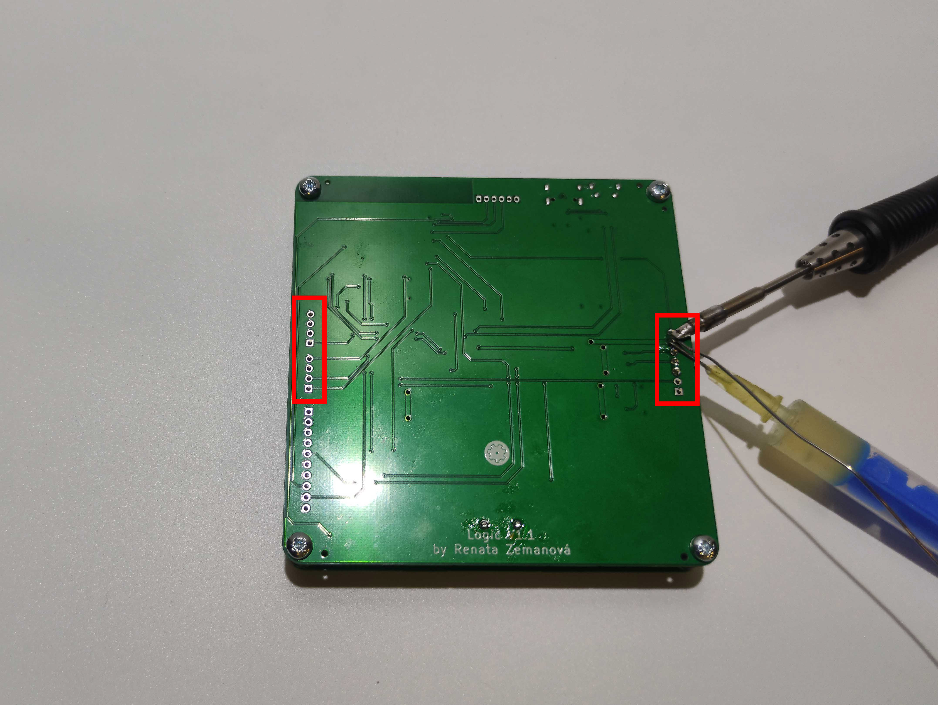
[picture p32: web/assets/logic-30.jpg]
<br>
20. Solder the sockets.
<hr>

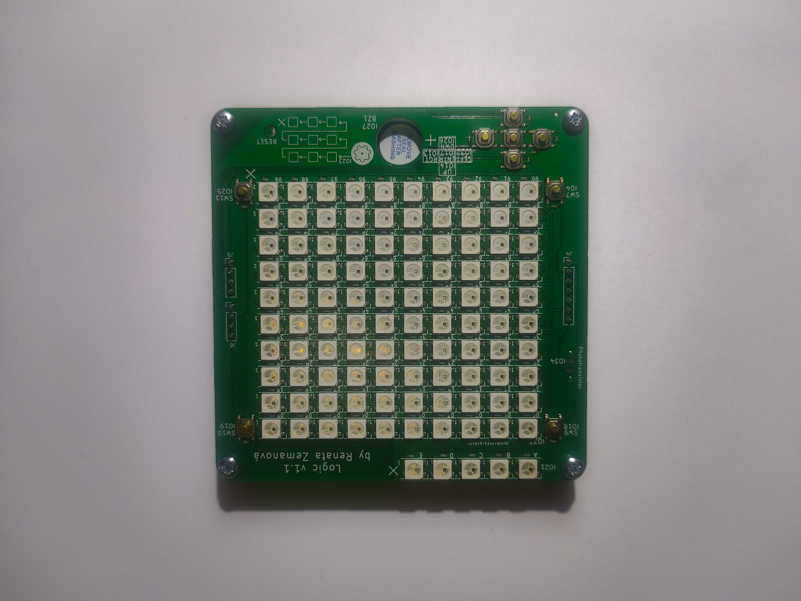
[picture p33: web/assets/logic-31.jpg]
<br>
21. Finished Logic – front view.
<hr>

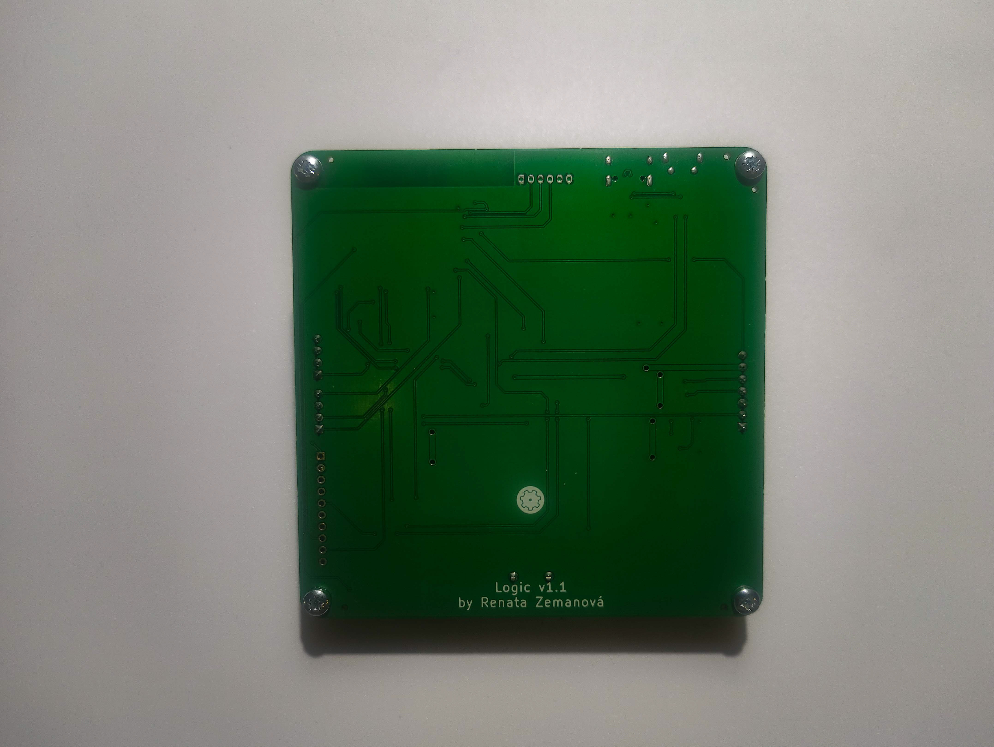
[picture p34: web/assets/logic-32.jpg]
<br>
22. Finished Logic – back view.
<hr>

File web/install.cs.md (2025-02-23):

# Software Development Kit

## Stručná verze pro zkušené vývojáře

Logic je řízený mikrokontrolérem ESP32. Doporučujeme použít
[nástroj PlatformIO](https://platformio.org/) jako vývojové prostředí, protože
umí automaticky nainstalovat potřebný toolchain a další závislosti. Navíc se
snadno integruje do mnoha existujících textových editorů a IDE.

Poskytujeme [knihovnu ovladačů](https://github.com/RoboticsBrno/Logic_library)
pro desku. Můžete ji ve svých projektech v PlatformIO použít tak, že do souboru
`platformio.ini` přidáte tento řádek:

```
lib_deps = https://github.com/RoboticsBrno/Logic_library
```

Knihovna nabízí [několik příkladů](https://github.com/RoboticsBrno/Logic_library/tree/main/examples),
[projektovou šablonu](https://github.com/RoboticsBrno/Logic_library/tree/main/examples/_TEMPLATE)
a [dokumentaci](https://roboticsbrno.github.io/Logic_library/). Také je k dispozici
[rychlý přehled všech funkcionalit](code/utils.md).

## Krok za krokem

Pokud jste začátečníci, možná vám přijde vhod následující podrobný návod. Je primárně
zaměřený na uživatele Windows (jak víte, vše týkající se vývoje je na tomto
systému obvykle složitější). Budete potřebovat nainstalovat:

1. Editor [Visual Studio Code](https://code.visualstudio.com/Download)
1. Python
    1. Pro Windows 8 a vyšší musíte stáhnout Python z [Windows Store](https://www.microsoft.com/en-us/p/python-39/9p7qfqmjrfp7)
    1. Pro Windows 7 potřebujete [Python 3.8.10](https://www.python.org/ftp/python/3.8.10/python-3.8.10-amd64.exe)
2. [Git pro správu verzí](https://git-scm.com/download/win)
3. USB ovladače ([Windows 7](https://www.silabs.com/documents/public/software/CP210x_Windows_Drivers.zip),
[Windows 8 a vyšší](https://www.silabs.com/documents/public/software/CP210x_Universal_Windows_Driver.zip))
4. Plugin PlatformIO pro Visual Studio Code

## 1. Visual Studio Code
Toto je editor, ve kterém budete upravovat své programy. [Stáhněte jej odtud](https://code.visualstudio.com/Download) a nainstalujte.

## 2. Python

Počítač musí mít nainstalovaný Python.

#### Windows 8, Windows 10

Je **nezbytné**, abyste Python nainstalovali přes Windows Store, jinak
PlatformIO nebude fungovat správně. Můžete použít [přímý odkaz do Windows
Store](https://www.microsoft.com/en-us/p/python-39/9p7qfqmjrfp7).

#### Windows 7

[Stáhněte Python
3.8](https://www.python.org/ftp/python/3.8.10/python-3.8.10-amd64.exe) (novější
verze Pythonu na Windows 7 nefungují) a nainstalujte jej. Během instalace
se ujistěte, že je zaškrtnuto "Add to PATH".

## 3. Git

[Stáhněte Git](https://git-scm.com/download/win) a nainstalujte ho. Všechny
možnosti můžete ponechat na výchozích hodnotách.

## 4. Ovladače pro Logic

Stáhněte ovladače:

* [Windows 8, Windows 10](https://www.silabs.com/documents/public/software/CP210x_Universal_Windows_Driver.zip)
* [Windows 7](https://www.silabs.com/documents/public/software/CP210x_Windows_Drivers.zip)

Je třeba rozbalit celý archiv a spustit soubor `CP210xVCPInstaller_x64.exe`. Poté
se řídit zobrazeným průvodcem.

## 5. Platform.io IDE Extension
Otevřete Visual Studio Code a nainstalujte rozšíření PlatformIO:

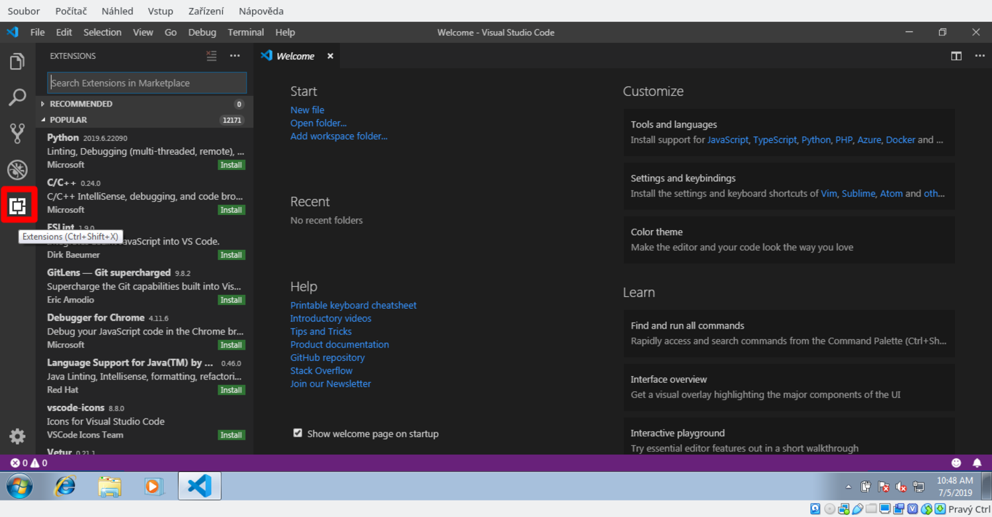
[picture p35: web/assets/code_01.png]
<br>
1. Otevřete VSCode a vlevo klikněte na tlačítko Extensions.
<hr>

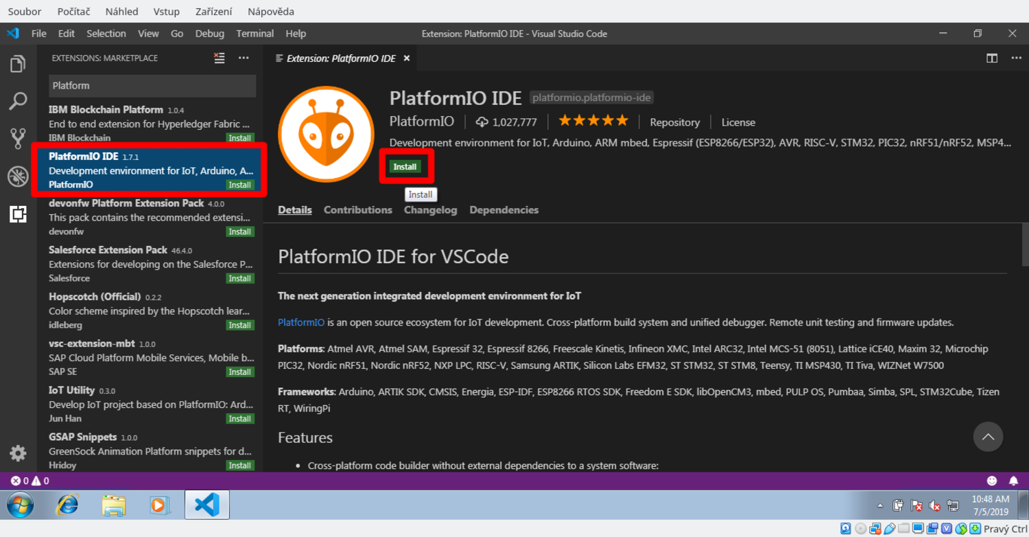
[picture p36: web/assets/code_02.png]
<br>
2. Nainstalujte rozšíření PlatformIO IDE.
<hr>

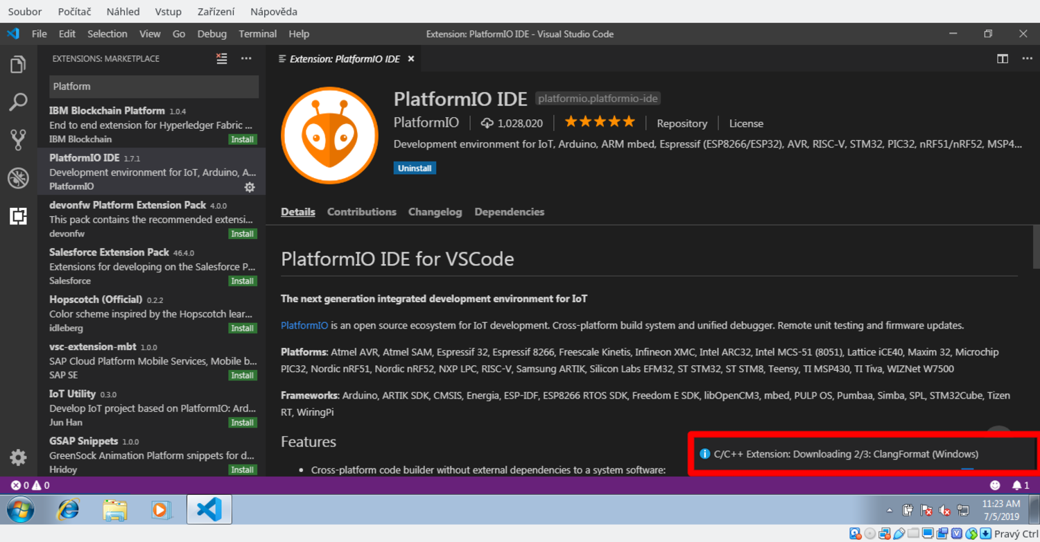
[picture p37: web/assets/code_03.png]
<br>
3. Počkejte, než se nainstalují všechny balíčky.
<hr>

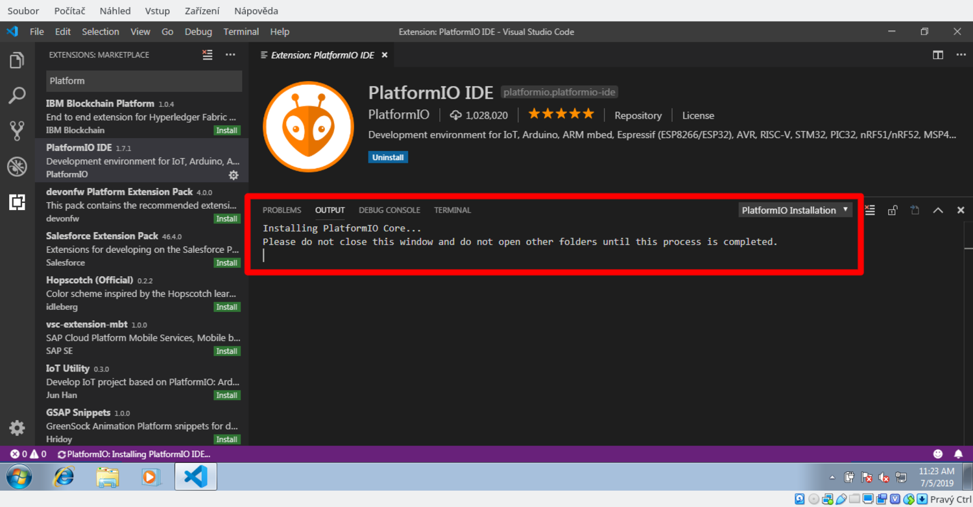
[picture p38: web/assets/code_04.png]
<br>
4. Následně vyčkejte na instalaci PlatformIO Core. Může to chvíli trvat.
<hr>

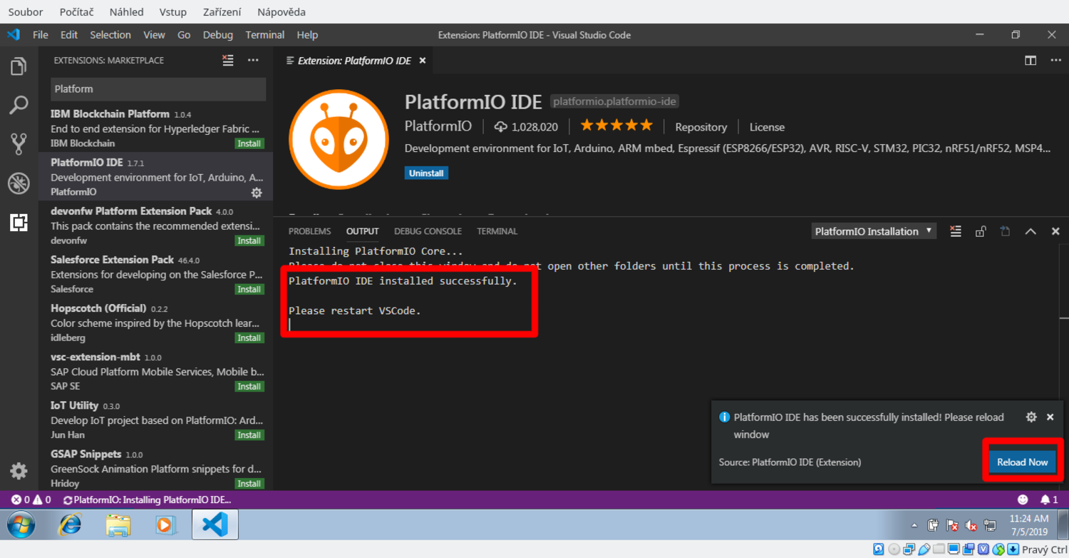
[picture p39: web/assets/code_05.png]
<br>
5. Jakmile je vše dokončeno, restartujte editor.
<hr>

## 6. Hotovo!

Nyní byste měli být připraveni začít vyvíjet vlastní hry pro Logic! Můžete začít
[příkladovými projekty](https://github.com/RoboticsBrno/Logic_library/tree/main/examples).
Otevřete je pomocí `File` -> `Open Folder`.

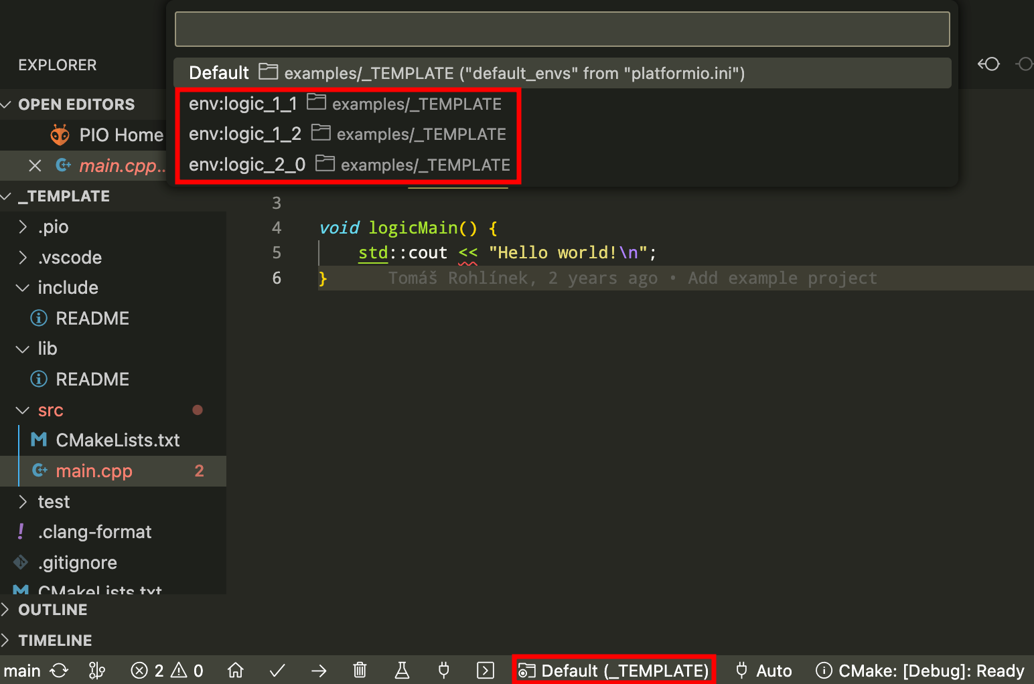
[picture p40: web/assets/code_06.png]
<br>
Po otevření příkladu je potřeba nastavit verzi Logic. Klikněte na `Defaul <PROJECT>` a vyberte svou verzi Logic.

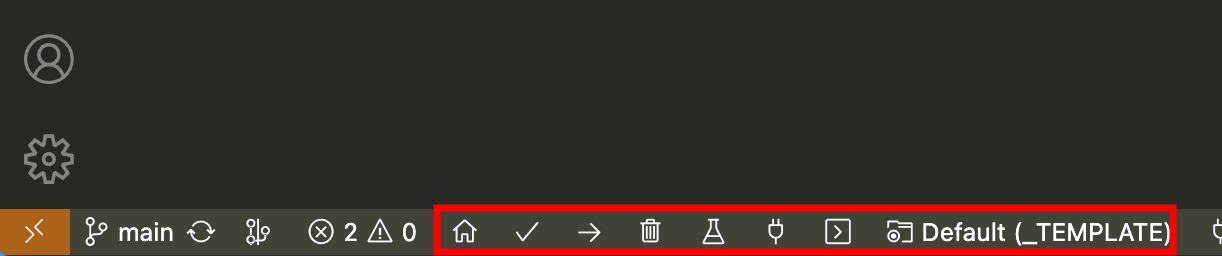
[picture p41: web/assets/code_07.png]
<br>
Poté můžete příklad zkompilovat a nahrát do svého Logic. K tomu použijte tlačítka v levém dolním rohu.

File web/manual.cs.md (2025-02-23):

# Návod na sestavení

RoboSvit schéma<br>
1. Připravíme si potřebný materiál podle fotky
<hr>

RoboSvit schéma<br>
2. Vložíme piezo do desky podle obrázku (pozor na otočení součástky)
<hr>

RoboSvit schéma<br>
3. Připájíme piezo k desce
<hr>

RoboSvit schéma<br>
4. Pomocí štípacích kleští zastřihneme přečnívající nožičky
<hr>

RoboSvit schéma<br>
5. Ustřihneme si dutinky a pinheady podle zadání.
	- 2x pinhead a dutinky o délce 4 piny
	- 1x pinhead a dutinky o délce 7 pinů 
<hr>

RoboSvit schéma<br>
6.  Pomocí zalamovacího nože si opatrně začistíme okraje
<hr>

RoboSvit schéma<br>
7. Začištěné dílky
<hr>

RoboSvit schéma<br>
8.  Pinheady zastrčíme delší stranou do dutinek
<hr>

RoboSvit schéma<br>
9. Zastrčíme dílky do desky dutinkami napřed. Nachystáme si 4 šroubky
<hr>

RoboSvit schéma<br>
10.  Vložíme šroubky do desky a nachystáme si podložky
<hr>

RoboSvit schéma<br>
11. Vložíme na šrouby nachystané podložky
<hr>

RoboSvit schéma<br>
12.   Nachystáme si 4 distanční sloupky a našroubujeme je na šrouby
<hr>

RoboSvit schéma<br>
13.  Nachystáme si podložky
<hr>

RoboSvit schéma<br>
14.  Podložky položíme na distanční sloupky a připravíme si další desku
<hr>

RoboSvit schéma<br>
15.  Desky nasadíme na sebe tak, aby nám seděly díry a pinheady
<hr>

RoboSvit schéma<br>
16. Připravíme si 4 šroubky
<hr>

RoboSvit schéma<br>
17. Přišroubujeme vrchní desku (pozor na podložky)
<hr>

RoboSvit schéma<br>
18.  Zkontrolujte si, že pinheady směřují k vrchní desce s ledkami a dutinky leží na spodní desce
<hr>

RoboSvit schéma<br>
19.  Zapájíme pinheady na horní straně Logicu
<hr>

RoboSvit schéma<br>
20.  Zapájíme dutinky na spodní straně Logicu
<hr>

RoboSvit schéma<br>
21. Hotový logic zepředu
<hr>

RoboSvit schéma<br>
22. Hotový logic zezadu
<hr>

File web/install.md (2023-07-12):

# Software Development Kit

## TLDR Version for the Skilled Developers

Logic is powered by the ESP32 microcontroller. We recommend using
[PlatformIO](https://platformio.org/) as the development tool as it can install
toolchain and other dependencies automatically. Also, it nicely integrates into
many existing text editors and IDEs.

We provide a [driver library](https://github.com/RoboticsBrno/Logic_library) for
the board. You can use it in your PlatformIO projects by adding the following line in your `platformio.ini` project file:

```
lib_deps = https://github.com/RoboticsBrno/Logic_library
```

The library provides [several
examples](https://github.com/RoboticsBrno/Logic_library/tree/main/examples),
[project
template](https://github.com/RoboticsBrno/Logic_library/tree/main/examples/_TEMPLATE)
and [documentation](https://roboticsbrno.github.io/Logic_library/). There is also a [quick overview of the whole functionality](code/utils.md).

## Step-by-step guide

If you are a beginner, you might find the following step-by-step tutorial handy.
The tutorial targets primarily Windows users (as you know, everything
development-related is more complicated on this system). You will need to install:

1. Editor [Visual Studio Code](https://code.visualstudio.com/Download)
1. Python
    1. For Windows 8 and higher, you need to download Python from [Windows Store](https://www.microsoft.com/en-us/p/python-39/9p7qfqmjrfp7)
    1. For Windows 7 you will need [Python 3.8.10](https://www.python.org/ftp/python/3.8.10/python-3.8.10-amd64.exe)
2. [Git version control](https://git-scm.com/download/win)
3. USB drivers ([Windows 7](https://www.silabs.com/documents/public/software/CP210x_Windows_Drivers.zip), [Windows 8 and higher](https://www.silabs.com/documents/public/software/CP210x_Universal_Windows_Driver.zip))
4. PlatformIO plugin for Visual Studio Code

## 1. Visual Studio Code
This is the editor you will use for editing programs. [Download it from here
](https://code.visualstudio.com/Download) and install it.

## 2. Python

The computer has to have the Python programming language runtime installed.

#### Windows 8, Windows 10

It is **required that you install Python via Window Store**, otherwise
PlatformIO will not work properly. You can use [direct link to Windows
Store](https://www.microsoft.com/en-us/p/python-39/9p7qfqmjrfp7) to obtain it.

#### Windows 7

[Download Python
3.8](https://www.python.org/ftp/python/3.8.10/python-3.8.10-amd64.exe) (newer
Pythons will not work on Windows 7) and install it. Make sure that "Add to PATH" is
checked during the installation.

## 3. Git

[Download Git](https://git-scm.com/download/win) and install it. All options can
be left on default.

## 4. Logic drivers

Download the drivers:

* [Windows 8, Windows 10](https://www.silabs.com/documents/public/software/CP210x_Universal_Windows_Driver.zip)
* [Windows 7](https://www.silabs.com/documents/public/software/CP210x_Windows_Drivers.zip)

You have to to extract the whole archive and run the file `CP210xVCPInstaller_x64.exe`. Follow the guide.

## 5. Platform.io IDE Extension
Open Visual Studio Code and install platform.io extension:

VSCode extension<br>
1. Open VSCode and click the Extensions button on the left panel.
<hr>

VSCode extension<br>
2. Install PlatformIO IDE extension.
<hr>

VSCode extension<br>
3. Wait until all packages are installed.
<hr>

VSCode extension<br>
4. Then also wait for the installation of PlatformIO Core. It can take a while.
<hr>

VSCode extension<br>
5. Once everything is completed, proceed with restart.
<hr>

## 6. Finished!

Now you should be ready to start developing your own Logic games! You can start
with [example
projects](https://github.com/RoboticsBrno/Logic_library/tree/main/examples).
Open the examples using `File` -> `Open Folder`.

VSCode extension<br>
After opening the example, you have to configure your Logic version. Click to the `Defaul <PROJECT>` and choose your Logic version.

VSCode extension<br>
Then you can build and upload the example to your Logic. Use the buttons in the bottom left corner to do so.

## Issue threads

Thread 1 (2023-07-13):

Pullupy na SD kartě

Tasssadar, 2023-07-13:
Na revizi 2.0 jsou špatně pullupy (jsou to pulldowny..), a funguje tedy pouze SDSPI protokol. Pro SDMMC je potřeba tohle:

| Pin | Pullup |
| ---  | ---- |
| CLK | žádný |
| CMD | 10k na 3.3v |
| DAT0 | 10k na 3.3v |
| DAT1 | 10k na 3.3v - ano, i když se nepoužívá |
| DAT2 | 10k na 3.3v - ano, i když se nepoužívá |
| DAT3/CD | 10k na 3.3v |

S touto konfigurací funguje jak SDMMC (20 i 40 MHz), tak SDSPI, tak Arduino.

Ref: https://docs.espressif.com/projects/esp-idf/en/latest/esp32s3/api-reference/peripherals/sd_pullup_requirements.html

Closed 2024-09-09.

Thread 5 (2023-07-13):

Add setup instructions for Linux

mukrop, 2023-07-13:
Currently, all instructions presume Windows machines. Many (most?) of the people to who Logics get via Red Hat will be Linux users. I see adding Linux alternatives to the instructions quite low-cost with high added value.

My experience (from setting up everything on Fedora 38):
* Setting up VS Code is pretty standardized (download package from the website or a distro version).
* Similarly with Python and git.
* The driver does not need to be installed, it's a part of the Linux kernel since v2.6.12 ([more details](https://community.silabs.com/s/article/cp210x-driver-in-the-linux-kernel?language=en_US))
* PlatformIO installation is the same.
* However, udev.rules need to be installed for PlatformIO ([official manual](https://docs.platformio.org/en/latest/core/installation/udev-rules.html#platformio-udev-rules)), otherwise the device cannot be seen in PIO's "Devices" view (this can be mentioned as a diagnostic).
* I would also add the final remark (for all OSes) regarding uploading and running the program: What USB port to use, that the program should run automatically after being uploaded to the board, and maybe even a warning that some USB cables are charging-only (a dumb information, true, but it took me a while to realize this was one of the errors I was doing).

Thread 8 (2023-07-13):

A testsuite example

mukrop, 2023-07-13:
In the process of getting the board to work, I'd appreciate a "testuite example" that used most/all its functions (be it only in a dumb sequence). E.g. something like testing all colors fullscreen, all buttons, progress bar, buzzer, creating a WiFi AP, being Bluetooth findable, etc.

(I do understand this would probably need a significant programming effort on top of existing programs.)

haberturdeur, 2023-07-14:
Everything except the Bluetooth part would ve quite easy to implement (just put together some of the already existing ones). We already have a WiFi library, so we just need to adapt that. Which leaves the Bluetooth. Which we have no library for yet AFAIK, and we don't want to use the Arduino one...

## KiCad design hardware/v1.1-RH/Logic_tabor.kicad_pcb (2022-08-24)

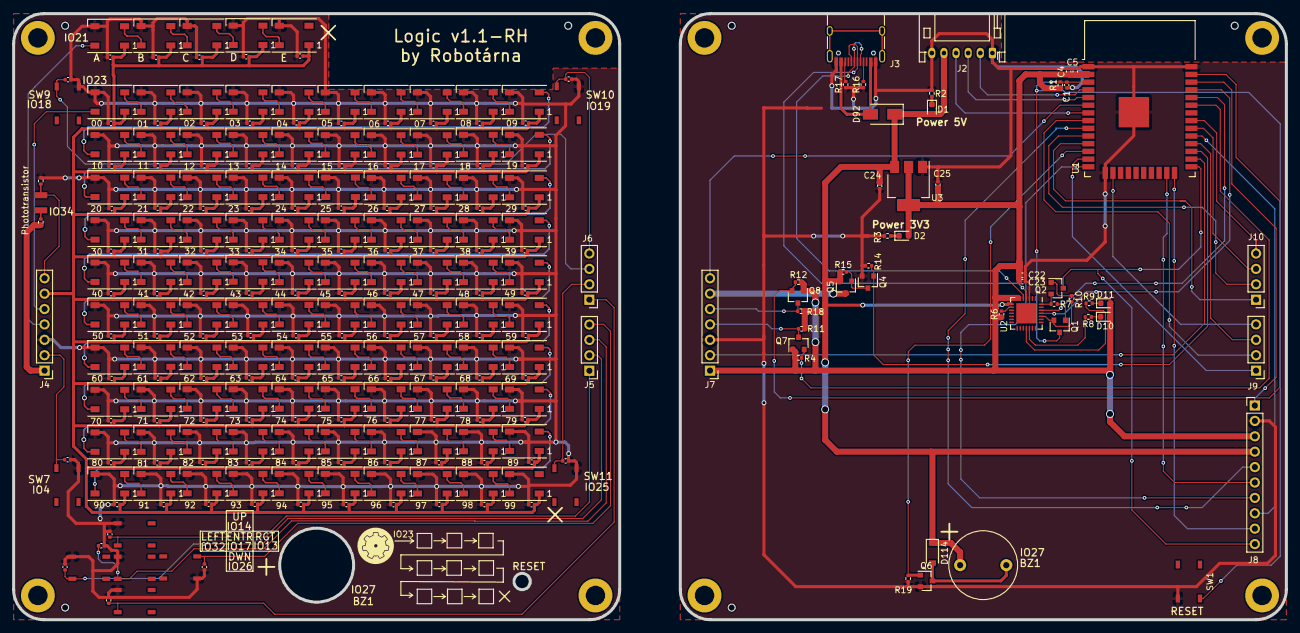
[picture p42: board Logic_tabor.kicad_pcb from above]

Board: 2 copper layers, 100.0 x 100.0 mm, 294 parts (1 on the bottom side), 170 nets.

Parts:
B1, B2: Board
BZ1: Buzzer; PIEZO
C1: 1u; C_0402_1005Metric
C2, C3, C5, C6, C7, C8, C9, C10, C15, C16, C21, C23, C31, C32, C33, C34, C35, C36, C37, C38, C39, C40, C41, C42, C43, C44, C45, C46, C47, C48, C49, C50, C51, C52, C53, C54, C55, C56, C57, C58, C59, C60, C61, C62, C63, C64, C65, C66, C67, C68, C69, C70, C71, C72, C73, C74, C75, C76, C77, C78, C79, C80, C81, C82, C83, C84, C85, C86, C87, C88, C89, C90, C91, C92, C93, C94, C95, C96, C97, C98, C99, C100, C101, C102, C103, C104, C105, C106, C107, C108, C109, C110, C111, C112, C113, C114, C115, C116, C117, C118, C119, C120, C121, C122, C123, C124, C125: 100n; C_0402_1005Metric
C4, C22, C24, C25: 10u; C_0402_1005Metric
C11, C12, C13, C14, C17, C18, C19, C20, C126: 10n; C_0402_1005Metric
D1, D2, D10, D11: green; LED_0603_1608Metric
D3, D4, D5, D6, D12, D13, D14, D15, D16, D17, D18, D19, D20, D21, D22, D23, D24, D25, D26, D27, D28, D29, D30, D31, D32, D33, D34, D35, D36, D37, D38, D39, D40, D41, D42, D43, D44, D45, D46, D47, D48, D49, D50, D51, D52, D53, D54, D55, D56, D57, D58, D59, D60, D61, D62, D63, D64, D65, D66, D67, D68, D69, D70, D71, D72, D73, D74, D75, D76, D77, D78, D79, D80, D81, D82, D83, D84, D85, D86, D87, D88, D89, D90, D91, D93, D94, D95, D96, D97, D98, D99, D100, D101, D102, D103, D104, D105, D106, D107, D108, D109, D110, D111, D112, D113: WS2812C; LED_WS2812B_PLCC4_5.0x5.0mm_P3.2mm
D92: DIODE; D_SMA
D114: D_Schottky; D_SOD-123
DRA1, DRA2: Logo_Robotarna; RobotarnaLogo-6mm
H1, H2, H3, H4, H5, H6, H7, H8: MountingHole; MountingHole_3.2mm_M3_DIN965_Pad
J2: Conn_01x06_Male; JST_PH_S6B-PH-K_1x06_P2.00mm_Horizontal
J3: USB_C_Receptacle_USB2.0; USB_C_Receptacle_HRO_TYPE-C-31-M-12
J4: Conn_01x07_Female; PinHeader_1x07_P2.54mm_Vertical
J5, J6: Conn_01x04_Female; PinHeader_1x04_P2.54mm_Vertical
J7: Conn_01x07_Male; PinHeader_1x07_P2.54mm_Vertical
J8: Conn_01x10_Male; PinHeader_1x10_P2.54mm_Vertical
J9, J10: Conn_01x04_Male; PinHeader_1x04_P2.54mm_Vertical
Q1, Q2: Q_NPN_BEC; SOT-23
Q3: Q_Photo_NPN; SMD,3.5x2.8x1.9mm
Q4, Q6, Q7, Q8: Q_NMOS_GSD; SOT-23
Q5: Q_PMOS_GSD; SOT-23
R1, R2, R3, R4, R6, R7, R8, R9, R10, R11, R12, R13, R18: 10k; R_0402_1005Metric
R5: 22k; R_0402_1005Metric
R14, R15, R19: 100k; R_0402_1005Metric
R16, R17: 5k1; R_0402_1005Metric
SW1, SW2, SW3, SW4, SW5, SW7, SW8, SW9, SW10, SW11: button; Tactile_switch
U1: ESP32-WROOM-32
U2: CP2102N-A01-GQFN28; QFN-28-1EP_5x5mm_P0.5mm_EP3.35x3.35mm
U3: AMS1117-3.3; SOT-223-3_TabPin2

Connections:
5V: BZ1.1 (-), C24.1, D1.2 (A), D92.1 (K), D114.1 (K), J2.5, J8.4, Q5.2 (S), R11.1, R15.1, R18.1, U2.8 (VBUS), U3.3 (VI)
/elektronika.sch/3V3: C4.2, C5.2, C22.2, C23.2, C25.1, D2.2 (A), D10.2 (A), D11.2 (A), J7.1, J8.3, Q7.1 (G), Q8.1 (G), R1.1, R4.1, R6.1, R12.1, U1.2 (VDD), U2.6 (VDD), U2.7 (REGIN), U3.2 (VO)
/elektronika.sch/DATA_HERNI_LED: J7.5, Q8.3 (D), R18.2
/elektronika.sch/DATA_ZADANI_LED: J7.4, Q7.3 (D), R11.2
/elektronika.sch/GND: C1.2, C4.1, C5.1, C22.1, C23.1, C24.2, C25.2, J2.1, J2.6, J3.A1 (GND), J3.A12 (GND), J3.B1 (GND), J3.B12 (GND), J7.3, J8.2, Q4.2 (S), Q6.2 (S), R2.1, R3.1, R14.2, R16.1, R17.1, R19.1, SW1.2, U1.1 (GND), U1.15 (GND), U1.38 (GND), U1.39 (GND), U2.3 (GND), U2.29 (GND), U3.1 (GND)
/elektronika.sch/SENZOR_SVETLA: J7.7, U1.6 (IO34)
/elektronika.sch/SW_2: J9.3, U1.28 (IO17)
/elektronika.sch/SW_3: J9.4, U1.16 (IO13)
/elektronika.sch/SW_4: J9.2, U1.8 (IO32)
/elektronika.sch/SW_5: J9.1, U1.13 (IO14)
/elektronika.sch/SW_7: J7.2, U1.26 (IO4)
/elektronika.sch/SW_8: J10.1, U1.11 (IO26)
/elektronika.sch/SW_9: J10.3, U1.30 (IO18)
/elektronika.sch/SW_10: J10.4, U1.31 (IO19)
/elektronika.sch/SW_11: J10.2, U1.10 (IO25)
/elektronika.sch/V_LED_1: J7.6, Q5.3 (D)
/ovladaci_prvky.sch/3V3: J4.1, R5.1
/ovladaci_prvky.sch/DATA_HERNI_LED: D12.4 (DIN), J4.5
/ovladaci_prvky.sch/DATA_ZADANI_LED: D3.4 (DIN), J4.4
/ovladaci_prvky.sch/GND: C2.2, C3.2, C6.2, C7.2, C8.2, C9.2, C10.2, C11.1, C12.1, C13.1, C14.1, C15.2, C16.2, C17.1, C18.1, C19.1, C20.1, C21.2, C31.2, C32.2, C33.2, C34.2, C35.2, C36.2, C37.2, C38.2, C39.2, C40.2, C41.2, C42.2, C43.2, C44.2, C45.2, C46.2, C47.2, C48.2, C49.2, C50.2, C51.2, C52.2, C53.2, C54.2, C55.2, C56.2, C57.2, C58.2, C59.2, C60.2, C61.2, C62.2, C63.2, C64.2, C65.2, C66.2, C67.2, C68.2, C69.2, C70.2, C71.2, C72.2, C73.2, C74.2, C75.2, C76.2, C77.2, C78.2, C79.2, C80.2, C81.2, C82.2, C83.2, C84.2, C85.2, C86.2, C87.2, C88.2, C89.2, C90.2, C91.2, C92.2, C93.2, C94.2, C95.2, C96.2, C97.2, C98.2, C99.2, C100.2, C101.2, C102.2, C103.2, C104.2, C105.2, C106.2, C107.2, C108.2, C109.2, C110.2, C111.2, C112.2, C113.2, C114.2, C115.2, C116.2, C117.2, C118.2, C119.2, C120.2, C121.2, C122.2, C123.2, C124.2, C125.2, C126.1, D3.3 (VSS), D4.3 (VSS), D5.3 (VSS), D6.3 (VSS), D12.3 (VSS), D13.3 (VSS), D14.3 (VSS), D15.3 (VSS), D16.3 (VSS), D17.3 (VSS), D18.3 (VSS), D19.3 (VSS), D20.3 (VSS), D21.3 (VSS), D22.3 (VSS), D23.3 (VSS), D24.3 (VSS), D25.3 (VSS), D26.3 (VSS), D27.3 (VSS), D28.3 (VSS), D29.3 (VSS), D30.3 (VSS), D31.3 (VSS), D32.3 (VSS), D33.3 (VSS), D34.3 (VSS), D35.3 (VSS), D36.3 (VSS), D37.3 (VSS), D38.3 (VSS), D39.3 (VSS), D40.3 (VSS), D41.3 (VSS), D42.3 (VSS), D43.3 (VSS), D44.3 (VSS), D45.3 (VSS), D46.3 (VSS), D47.3 (VSS), D48.3 (VSS), D49.3 (VSS), D50.3 (VSS), D51.3 (VSS), D52.3 (VSS), D53.3 (VSS), D54.3 (VSS), D55.3 (VSS), D56.3 (VSS), D57.3 (VSS), D58.3 (VSS), D59.3 (VSS), D60.3 (VSS), D61.3 (VSS), D62.3 (VSS), D63.3 (VSS), D64.3 (VSS), D65.3 (VSS), D66.3 (VSS), D67.3 (VSS), D68.3 (VSS), D69.3 (VSS), D70.3 (VSS), D71.3 (VSS), D72.3 (VSS), D73.3 (VSS), D74.3 (VSS), D75.3 (VSS), D76.3 (VSS), D77.3 (VSS), D78.3 (VSS), D79.3 (VSS), D80.3 (VSS), D81.3 (VSS), D82.3 (VSS), D83.3 (VSS), D84.3 (VSS), D85.3 (VSS), D86.3 (VSS), D87.3 (VSS), D88.3 (VSS), D89.3 (VSS), D90.3 (VSS), D91.3 (VSS), D93.3 (VSS), D94.3 (VSS), D95.3 (VSS), D96.3 (VSS), D97.3 (VSS), D98.3 (VSS), D99.3 (VSS), D100.3 (VSS), D101.3 (VSS), D102.3 (VSS), D103.3 (VSS), D104.3 (VSS), D105.3 (VSS), D106.3 (VSS), D107.3 (VSS), D108.3 (VSS), D109.3 (VSS), D110.3 (VSS), D111.3 (VSS), D112.3 (VSS), D113.3 (VSS), J4.3, R13.2, SW2.2, SW3.2, SW4.2, SW5.2, SW7.2, SW8.2, SW9.2, SW10.2, SW11.2
/ovladaci_prvky.sch/SENZOR_SVETLA: J4.7, Q3.2 (E), R13.1
/ovladaci_prvky.sch/SW_2: C11.2, J5.3, SW2.1
/ovladaci_prvky.sch/SW_3: C12.2, J5.4, SW3.1
/ovladaci_prvky.sch/SW_4: C13.2, J5.2, SW4.1
/ovladaci_prvky.sch/SW_5: C14.2, J5.1, SW5.1
/ovladaci_prvky.sch/SW_7: C126.2, J4.2, SW7.1
/ovladaci_prvky.sch/SW_8: C17.2, J6.1, SW8.1
/ovladaci_prvky.sch/SW_9: C18.2, J6.3, SW9.1
/ovladaci_prvky.sch/SW_10: C19.2, J6.4, SW10.1
/ovladaci_prvky.sch/SW_11: C20.2, J6.2, SW11.1
/ovladaci_prvky.sch/V_LED_1: C2.1, C3.1, C6.1, C7.1, C8.1, C9.1, C10.1, C15.1, C16.1, C21.1, C31.1, C32.1, C33.1, C34.1, C35.1, C36.1, C37.1, C38.1, C39.1, C40.1, C41.1, C42.1, C43.1, C44.1, C45.1, C46.1, C47.1, C48.1, C49.1, C50.1, C51.1, C52.1, C53.1, C54.1, C55.1, C56.1, C57.1, C58.1, C59.1, C60.1, C61.1, C62.1, C63.1, C64.1, C65.1, C66.1, C67.1, C68.1, C69.1, C70.1, C71.1, C72.1, C73.1, C74.1, C75.1, C76.1, C77.1, C78.1, C79.1, C80.1, C81.1, C82.1, C83.1, C84.1, C85.1, C86.1, C87.1, C88.1, C89.1, C90.1, C91.1, C92.1, C93.1, C94.1, C95.1, C96.1, C97.1, C98.1, C99.1, C100.1, C101.1, C102.1, C103.1, C104.1, C105.1, C106.1, C107.1, C108.1, C109.1, C110.1, C111.1, C112.1, C113.1, C114.1, C115.1, C116.1, C117.1, C118.1, C119.1, C120.1, C121.1, C122.1, C123.1, C124.1, C125.1, D3.1 (VDD), D4.1 (VDD), D5.1 (VDD), D6.1 (VDD), D12.1 (VDD), D13.1 (VDD), D14.1 (VDD), D15.1 (VDD), D16.1 (VDD), D17.1 (VDD), D18.1 (VDD), D19.1 (VDD), D20.1 (VDD), D21.1 (VDD), D22.1 (VDD), D23.1 (VDD), D24.1 (VDD), D25.1 (VDD), D26.1 (VDD), D27.1 (VDD), D28.1 (VDD), D29.1 (VDD), D30.1 (VDD), D31.1 (VDD), D32.1 (VDD), D33.1 (VDD), D34.1 (VDD), D35.1 (VDD), D36.1 (VDD), D37.1 (VDD), D38.1 (VDD), D39.1 (VDD), D40.1 (VDD), D41.1 (VDD), D42.1 (VDD), D43.1 (VDD), D44.1 (VDD), D45.1 (VDD), D46.1 (VDD), D47.1 (VDD), D48.1 (VDD), D49.1 (VDD), D50.1 (VDD), D51.1 (VDD), D52.1 (VDD), D53.1 (VDD), D54.1 (VDD), D55.1 (VDD), D56.1 (VDD), D57.1 (VDD), D58.1 (VDD), D59.1 (VDD), D60.1 (VDD), D61.1 (VDD), D62.1 (VDD), D63.1 (VDD), D64.1 (VDD), D65.1 (VDD), D66.1 (VDD), D67.1 (VDD), D68.1 (VDD), D69.1 (VDD), D70.1 (VDD), D71.1 (VDD), D72.1 (VDD), D73.1 (VDD), D74.1 (VDD), D75.1 (VDD), D76.1 (VDD), D77.1 (VDD), D78.1 (VDD), D79.1 (VDD), D80.1 (VDD), D81.1 (VDD), D82.1 (VDD), D83.1 (VDD), D84.1 (VDD), D85.1 (VDD), D86.1 (VDD), D87.1 (VDD), D88.1 (VDD), D89.1 (VDD), D90.1 (VDD), D91.1 (VDD), D93.1 (VDD), D94.1 (VDD), D95.1 (VDD), D96.1 (VDD), D97.1 (VDD), D98.1 (VDD), D99.1 (VDD), D100.1 (VDD), D101.1 (VDD), D102.1 (VDD), D103.1 (VDD), D104.1 (VDD), D105.1 (VDD), D106.1 (VDD), D107.1 (VDD), D108.1 (VDD), D109.1 (VDD), D110.1 (VDD), D111.1 (VDD), D112.1 (VDD), D113.1 (VDD), J4.6
/ovladaci_prvky.sch/herni_pole_LED.sch/1.sch/DATA_OUT: D16.2 (DOUT), D17.4 (DIN)
/ovladaci_prvky.sch/herni_pole_LED.sch/2.sch/DATA_OUT: D21.2 (DOUT), D22.4 (DIN)
/ovladaci_prvky.sch/herni_pole_LED.sch/3.sch/DATA_OUT: D26.2 (DOUT), D27.4 (DIN)
/ovladaci_prvky.sch/herni_pole_LED.sch/4.sch/DATA_OUT: D31.2 (DOUT), D32.4 (DIN)
/ovladaci_prvky.sch/herni_pole_LED.sch/5.sch/DATA_OUT: D36.2 (DOUT), D37.4 (DIN)
/ovladaci_prvky.sch/herni_pole_LED.sch/6.sch/DATA_OUT: D41.2 (DOUT), D42.4 (DIN)
/ovladaci_prvky.sch/herni_pole_LED.sch/7.sch/DATA_OUT: D46.2 (DOUT), D47.4 (DIN)
/ovladaci_prvky.sch/herni_pole_LED.sch/8.sch/DATA_OUT: D51.2 (DOUT), D52.4 (DIN)
/ovladaci_prvky.sch/herni_pole_LED.sch/10.sch/DATA_IN: D56.2 (DOUT), D57.4 (DIN)
/ovladaci_prvky.sch/herni_pole_LED.sch/10.sch/DATA_OUT: D61.2 (DOUT), D62.4 (DIN)
/ovladaci_prvky.sch/herni_pole_LED.sch/11.sch/DATA_OUT: D66.2 (DOUT), D67.4 (DIN)
/ovladaci_prvky.sch/herni_pole_LED.sch/12.sch/DATA_OUT: D71.2 (DOUT), D72.4 (DIN)
/ovladaci_prvky.sch/herni_pole_LED.sch/13.sch/DATA_OUT: D76.2 (DOUT), D77.4 (DIN)
/ovladaci_prvky.sch/herni_pole_LED.sch/14.sch/DATA_OUT: D81.2 (DOUT), D82.4 (DIN)
/ovladaci_prvky.sch/herni_pole_LED.sch/15.sch/DATA_OUT: D86.2 (DOUT), D87.4 (DIN)
/ovladaci_prvky.sch/herni_pole_LED.sch/16.sch/DATA_OUT: D91.2 (DOUT), D93.4 (DIN)
/ovladaci_prvky.sch/herni_pole_LED.sch/17.sch/DATA_OUT: D97.2 (DOUT), D98.4 (DIN)
/ovladaci_prvky.sch/herni_pole_LED.sch/18.sch/DATA_OUT: D102.2 (DOUT), D103.4 (DIN)
/ovladaci_prvky.sch/herni_pole_LED.sch/19.sch/DATA_OUT: D107.2 (DOUT), D108.4 (DIN)
DATA_HERNI_LED_LS: Q8.2 (S), R12.2, U1.37 (IO23)
DATA_ZADANI_LED_LS: Q7.2 (S), R4.2, U1.33 (IO21)
EN: C1.1, Q1.3 (C), R1.2, SW1.1, U1.3 (EN)
IO0: J8.10, Q2.3 (C), U1.25 (IO0)
IO2: J8.9, U1.24 (IO2)
IO5: J8.8, U1.29 (IO5)
IO12: J8.7, U1.14 (IO12)
IO15: J8.6, U1.23 (IO15)
IO22: J8.1, U1.36 (IO22)
IO33: J8.5, U1.9 (IO33)
unnamed: BZ1.2 (+), D114.2 (A), Q6.3 (D)
unnamed: D1.1 (K), R2.2
unnamed: D2.1 (K), R3.2
unnamed: D3.2 (DOUT), D4.4 (DIN)
unnamed: D4.2 (DOUT), D5.4 (DIN)
unnamed: D5.2 (DOUT), D6.4 (DIN)
unnamed: D10.1 (K), R8.1
unnamed: D11.1 (K), R9.1
unnamed: D12.2 (DOUT), D13.4 (DIN)
unnamed: D13.2 (DOUT), D14.4 (DIN)
unnamed: D14.2 (DOUT), D15.4 (DIN)
unnamed: D15.2 (DOUT), D16.4 (DIN)
unnamed: D17.2 (DOUT), D18.4 (DIN)
unnamed: D18.2 (DOUT), D19.4 (DIN)
unnamed: D19.2 (DOUT), D20.4 (DIN)
unnamed: D20.2 (DOUT), D21.4 (DIN)
unnamed: D22.2 (DOUT), D23.4 (DIN)
unnamed: D23.2 (DOUT), D24.4 (DIN)
unnamed: D24.2 (DOUT), D25.4 (DIN)
unnamed: D25.2 (DOUT), D26.4 (DIN)
unnamed: D27.2 (DOUT), D28.4 (DIN)
unnamed: D28.2 (DOUT), D29.4 (DIN)
unnamed: D29.2 (DOUT), D30.4 (DIN)
unnamed: D30.2 (DOUT), D31.4 (DIN)
unnamed: D32.2 (DOUT), D33.4 (DIN)
unnamed: D33.2 (DOUT), D34.4 (DIN)
unnamed: D34.2 (DOUT), D35.4 (DIN)
unnamed: D35.2 (DOUT), D36.4 (DIN)
unnamed: D37.2 (DOUT), D38.4 (DIN)
unnamed: D38.2 (DOUT), D39.4 (DIN)
unnamed: D39.2 (DOUT), D40.4 (DIN)
unnamed: D40.2 (DOUT), D41.4 (DIN)
unnamed: D42.2 (DOUT), D43.4 (DIN)
unnamed: D43.2 (DOUT), D44.4 (DIN)
unnamed: D44.2 (DOUT), D45.4 (DIN)
unnamed: D45.2 (DOUT), D46.4 (DIN)
unnamed: D47.2 (DOUT), D48.4 (DIN)
unnamed: D48.2 (DOUT), D49.4 (DIN)
unnamed: D49.2 (DOUT), D50.4 (DIN)
unnamed: D50.2 (DOUT), D51.4 (DIN)
unnamed: D52.2 (DOUT), D53.4 (DIN)
unnamed: D53.2 (DOUT), D54.4 (DIN)
unnamed: D54.2 (DOUT), D55.4 (DIN)
unnamed: D55.2 (DOUT), D56.4 (DIN)
unnamed: D57.2 (DOUT), D58.4 (DIN)
unnamed: D58.2 (DOUT), D59.4 (DIN)
unnamed: D59.2 (DOUT), D60.4 (DIN)
unnamed: D60.2 (DOUT), D61.4 (DIN)
unnamed: D62.2 (DOUT), D63.4 (DIN)
unnamed: D63.2 (DOUT), D64.4 (DIN)
unnamed: D64.2 (DOUT), D65.4 (DIN)
unnamed: D65.2 (DOUT), D66.4 (DIN)
unnamed: D67.2 (DOUT), D68.4 (DIN)
unnamed: D68.2 (DOUT), D69.4 (DIN)
unnamed: D69.2 (DOUT), D70.4 (DIN)
unnamed: D70.2 (DOUT), D71.4 (DIN)
unnamed: D72.2 (DOUT), D73.4 (DIN)
unnamed: D73.2 (DOUT), D74.4 (DIN)
unnamed: D74.2 (DOUT), D75.4 (DIN)
unnamed: D75.2 (DOUT), D76.4 (DIN)
unnamed: D77.2 (DOUT), D78.4 (DIN)
unnamed: D78.2 (DOUT), D79.4 (DIN)
unnamed: D79.2 (DOUT), D80.4 (DIN)
unnamed: D80.2 (DOUT), D81.4 (DIN)
unnamed: D82.2 (DOUT), D83.4 (DIN)
unnamed: D83.2 (DOUT), D84.4 (DIN)
unnamed: D84.2 (DOUT), D85.4 (DIN)
unnamed: D85.2 (DOUT), D86.4 (DIN)
unnamed: D87.2 (DOUT), D88.4 (DIN)
unnamed: D88.2 (DOUT), D89.4 (DIN)
unnamed: D89.2 (DOUT), D90.4 (DIN)
unnamed: D90.2 (DOUT), D91.4 (DIN)
unnamed: D92.2 (A), J3.A4 (VBUS), J3.A9 (VBUS), J3.B4 (VBUS), J3.B9 (VBUS)
unnamed: D93.2 (DOUT), D94.4 (DIN)
unnamed: D94.2 (DOUT), D95.4 (DIN)
unnamed: D95.2 (DOUT), D96.4 (DIN)
unnamed: D96.2 (DOUT), D97.4 (DIN)
unnamed: D98.2 (DOUT), D99.4 (DIN)
unnamed: D100.2 (DOUT), D101.4 (DIN)
unnamed: D99.2 (DOUT), D100.4 (DIN)
unnamed: D101.2 (DOUT), D102.4 (DIN)
unnamed: D103.2 (DOUT), D104.4 (DIN)
unnamed: D104.2 (DOUT), D105.4 (DIN)
unnamed: D105.2 (DOUT), D106.4 (DIN)
unnamed: D106.2 (DOUT), D107.4 (DIN)
unnamed: D108.2 (DOUT), D109.4 (DIN)
unnamed: D109.2 (DOUT), D110.4 (DIN)
unnamed: D110.2 (DOUT), D111.4 (DIN)
unnamed: D111.2 (DOUT), D112.4 (DIN)
unnamed: D6.2 (DOUT), D113.4 (DIN)
unnamed: J3.A5 (CC1), R16.2
unnamed: J3.A6 (D+), J3.B6 (D+), U2.4 (D+)
unnamed: J3.A7 (D-), J3.B7 (D-), U2.5 (D-)
unnamed: J3.B5 (CC2), R17.2
unnamed: Q1.1 (B), R7.1
unnamed: Q1.2 (E), R10.2, U2.24 (~RTS)
unnamed: Q2.1 (B), R10.1
unnamed: Q2.2 (E), R7.2, U2.28 (~DTR)
unnamed: Q3.1 (C), R5.2
unnamed: Q4.3 (D), Q5.1 (G), R15.2
unnamed: R6.2, U2.9 (~RSTb)
unnamed: R8.2, U2.19 (~TXT/GPIO.0)
unnamed: R9.2, U2.18 (~RXT/GPIO.1)
PIEZO: Q6.1 (G), R19.2, U1.12 (IO27)
RX_ESP: U1.34 (RXD0/IO3), U2.26 (TXD)
TX_ESP: U1.35 (TXD0/IO1), U2.25 (RXD)
VSTUP1: J2.3, U1.5 (SENSOR_VN)
VSTUP2: J2.2, U1.4 (SENSOR_VP)
VSTUP3: J2.4, U1.7 (IO35)
ZAPINANI_1_CAST_LED: Q4.1 (G), R14.1, U1.27 (IO16)

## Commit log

2022-02-17 v1.1 for RoboCamp 2021
    [LEDky100.sch, LEDky4.sch, LEDky40.sch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]
2022-02-17 deleted connector J2, changed location of switches SW7, 9, 10, 11, add library, change procesor - ESP32-WROVER,
    [LEDky100.sch, LEDky4.sch, LEDky40.sch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]
2022-08-24 Start v1.1-RH revision
    [LEDky5.kicad_sch, Logic_tabor.kicad_pcb, Logic_tabor.kicad_sch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]
2022-08-25 Final touch for the RH version
    [Logic_tabor.kicad_sch, elektronika.kicad_sch]
2022-08-25 Fix LED correction
    [LEDky5.kicad_sch, zadani_LED.kicad_sch]
2023-02-13 V2.0 ESP32_S3
    - ESP32_S3
    - two digilent connectors
    [ESP.kicad_sch, LEDky5.kicad_sch, Logic_tabor.kicad_sch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]
2023-02-15 Secondary button cross
    [ESP.kicad_sch, Logic_tabor.kicad_sch, elektronika.kicad_sch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]
2023-02-17 SD karta and factory files
    [ESP.kicad_sch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]
2023-06-12 RH v2 version
    [LED-CmtUser.gbr, LED-CuBottom.gbl, LED-CuTop.gtl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]
2023-06-12 Change piezo
    [LEDky5.kicad_sch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]
2023-06-20 Add .csv files
    [bom.csv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]
2023-12-05 Microphone and a few minor changes
    [ESP.kicad_sch, LEDky5.kicad_sch, Logic_tabor.kicad_sch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]
2024-03-11 Move C22 away from the SD card
    [Logic_tabor.kicad_sch, zadani_LED.kicad_sch]
2024-03-11 Small tidy up
    [ESP.kicad_sch, LEDky5.kicad_sch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]
2024-09-09 Fix PMOD conectors
    [elektronika.kicad_sch]
2024-09-10 Connector labels
2025-02-23 Add language switcher
